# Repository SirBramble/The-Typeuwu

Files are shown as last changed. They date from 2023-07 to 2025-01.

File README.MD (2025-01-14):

# The Typeuwu

The Typeuwu is a modular keyboard design that can be extended with magnetic modules. It also provides a connector for a optional Bluetooth and Battery module.\
The firmware is written in C++ and provides a recompile free key remapping with the AniMacro scripting language.

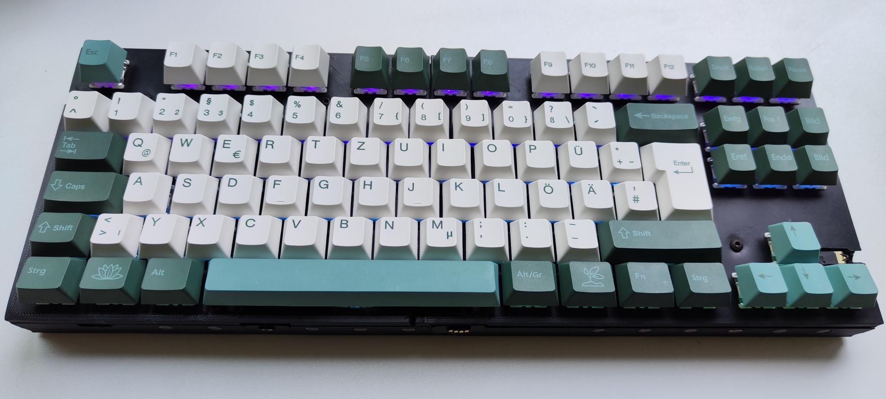
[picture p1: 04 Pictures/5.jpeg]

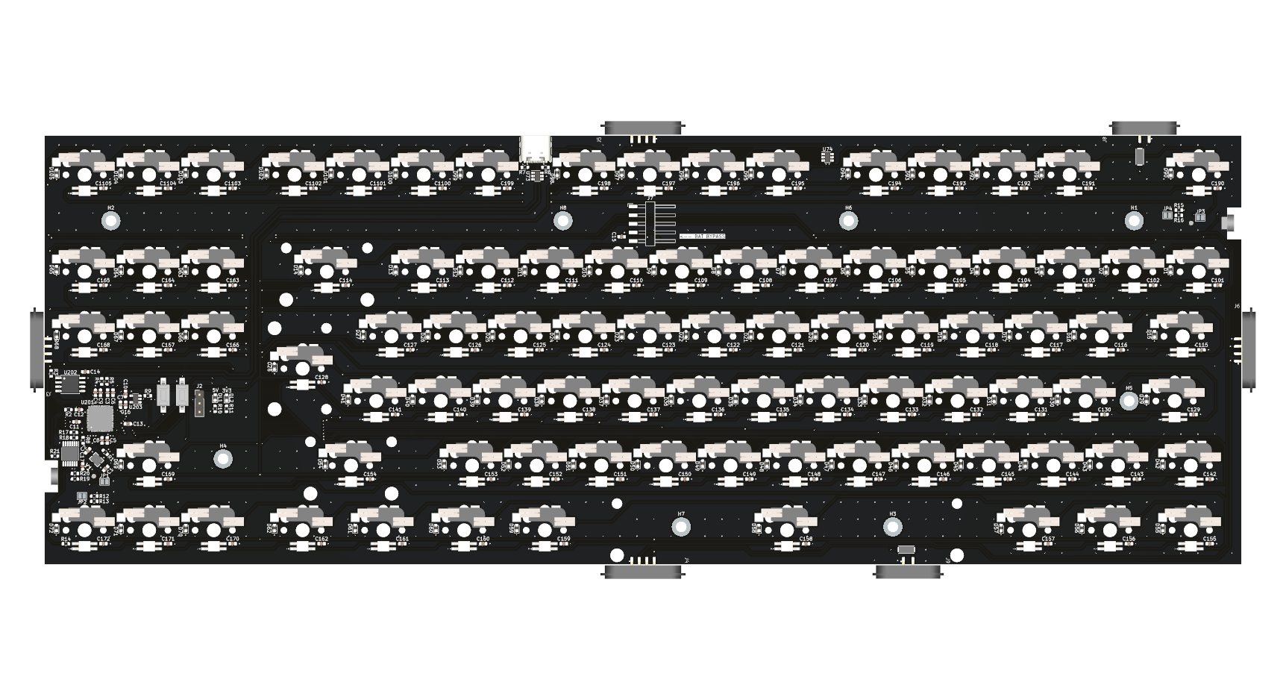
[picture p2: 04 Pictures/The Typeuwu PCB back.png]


## Hardware

The Typeuwu uses a RP2040 as the core processor, that polls the keyboard matrix, controls the LEDs and handles the communication between The keyboard and PC.

It also connects to the modules via magnetic pogo pin connectors located in the centre of each side. These provide the modules with power and expose the 5V level-shifted I2C lines.

Schematics can be found in ```/01 PCB/01 The Typeuwu PCB```.\
A PDF is available [```here```](01%20PCB/01%20The%20Typeuwu%20PCB/schematics/The%20Typeuwu.pdf).

## Firmware

The keyboard uses the custom written UWU (Universal Wordtyping Unit) Firmware that provides all needed interfaces for communicating with the Host and other modules.\
It also provides a parser for the 'AniMacro' scripting language, allowing the user to customise the key functionality from a config file located on the keyboards flash drive, without having to recompile the firmware.\

> [!IMPORTANT]  
> The firmware version included in this repository is deprecated. Though functional, further updates to the firmware will be posted to the [```UWU-Firmware```](https://github.com/SirBramble/UWU-Firmware) repository. Precompiled binary files are also available there.

### Uploading firmware

#### Precompiled firmware

To upload the precompiled binary, set the RP2040 into bootloader mode. This is done by first pressing the ```boot``` button, followed by either pressing the ```reset```button or performing a power cycle. The RP2040 should then mount as a flash drive named ```UF2```.\
Then either upload the Code using PIO or the Arduino IDE or copy the ```firmware.uf2``` file to the flash drive.

#### Compiling PIO

1. Make sure you have VSCode with the PlatformIO extension installed.
2. Clone the [```UWU-Firmware```](https://github.com/SirBramble/UWU-Firmware) repository (here: [github.com/SirBramble/UWU-Firmware](github.com/SirBramble/UWU-Firmware)).
3. Open the folder with PlatformIO.
   - PlatformIO should recognise it as a project and allow you to compile using either the VSCode interface or with the command ```platformio run```.
   - See [PlatformIO run documentation](https://docs.platformio.org/en/latest/core/userguide/cmd_run.html) for more information and possible arguments.
   - Any required library can either be added in the ```platformio.ini``` or copied to the ```lib``` (lib.h) and ```src``` (lib.c or lib.cpp) directory.

#### Compiling Arduino (deprecated)

1. Download the latest version of the Arduino IDE.
2. Install the [```arduino-pico```](https://github.com/earlephilhower/arduino-pico) board library.
    - You will also have to install the following librarys:
      - Adafruit NeoPixel (version: 1.12.0)
      - Adafruit SPIFlash (version: 4.3.1)
      - MIDI Library (version: 5.0.2)
3. Download the ```Typeuwu_Firmware``` folder.
4. Open the ```Typeuwu_Firmware.ino``` file with the Arduino IDE and either compile or upload directly.

## AniMacro scripting language

The 'AniMacro' scripting language allows the user to configure any Hardware Interface running the 'UWU firmware'.\
Configurations written in AniMacro are automatically loaded upon start-up and subsequently parsed using regular expressions. Additionally, the firmware can detect changes in the configuration file, facilitating its reload as needed, thereby enabling dynamic configuration adjustments at runtime.

A single configuration file accommodates configurations for various hardware UWU modules. The firmware selectively parses configurations pertinent to the currently connected hardware modules. This design choice allows for the seamless connection of multiple modules during runtime.

### Syntax

The 'AniMacro' syntax is based loosely on LaTeX syntax. A configuration for a specific module is wrapped in a ```begin``` and ```end``` qualifier:

```c
begin{module}
...
end{module}
```

Within a module configuration, multiple layers can be incorporated. Layers are a mechanism to implement diverse button configurations, facilitating dynamic switching between them at runtime. Layers can be added by typing ```Layer``` followed by the number of the layer:

```c
begin{module}
Layer x
...
end{module}
```

> [!IMPORTANT]
>By default the Firmware starts on layer 1. In the absence of a configured layer 1, the firmware remains inactive. It is advisable to consistently include a layer 1 configuration to ensure proper functionality.

All devices responsible for executing actions within a layer are designated using the ```Button``` keyword. Whether these devices are faders, potentiometers, or conventional buttons, they are uniformly referenced with the ```Button``` keyword.\
Buttons are implemented using the 'Button' keyword, followed by the button number, a colon, and a space. Subsequently, functionality can be added to the button by incorporating commands within the same line as the 'Button' keyword:

```c
begin{module}
Layer x
    Button a: commands
    Button b: commands
...
end{module}
```

Commands are categorized into several groups, which can be combined within a button configuration:

- Plain text:\
Entering plain text (e.g., "this is text123") utilizes the keyboard HID interface to type out the provided text.
    > [!NOTE]
    > Only ASCII characters are accepted in plain text. Non-ASCII characters (e.g. ```ä```) are managed with separate commands.
- ```\COMMAND``` with no arguments:\
    These commands serve as non-configurable placeholders for specific actions. For instance, pressing the 'Enter' key on the keyboard (```\ENTER_KEY```) or adding umlauts (```\ae``` => ```ä```).
- ```\COMMAND{}``` with arguments:\
    These commands are commonly employed to configure actions and callbacks within the firmware.\
    For example: ```\COLOR{const,green}``` would set the button to a constant green colour.\
    ```\MIDI_CC_KEY{16,1}\COLOR{midi,white}``` would configure a MIDI callback, binding the button to MIDI CC number 16 on MIDI channel 1. When the button is triggered, a MIDI message is dispatched to the host (PC), initiating an action. Subsequently, the host can relay back the state of the triggered action. The response from the host is then linked to the button colour, with a response greater than 126 denoting a triggered colour override, and a response of less than 126 signifying a reversion back to the layer default.

### List of commands

#### AniMacro commands

| Command | Description | Note |
| --- | --- | --- |
| Plain text | Types out the given text via the HID Interface | Only works with ASCII characters|
| ```\ae``` ```\oe``` ```\ue``` | Types out ```Umlauts``` (ä,ö,ü) | |
| ```\SZ_KEY``` | Sends keycode of ```ß``` key | |
| ```\GRAVE_KEY``` | Sends keycode of ```backtick``` ('´') key | |
| ```\CAPS_LOCK_KEY``` | Sends keycode of ```caps lock``` key | |
| ```\LSHIFT_KEY``` | Sends keycode of ```left shift``` key | |
| ```\RSHIFT_KEY``` | Sends keycode of ```right shift``` key | |
| ```\LCTRL_KEY``` | Sends keycode of ```left control``` key | For control combinations (e.g. ```CTRL``` + ```C```) refer to ```\STRG{char}```|
| ```\RCTRL_KEY``` | Sends keycode of ```right control``` key | For control combinations (e.g. ```CTRL``` + ```C```) refer to ```\STRG{char}```|
| ```\LATL_KEY``` | Sends keycode of ```left alt``` key | |
| ```\RATL_KEY```| Sends keycode of ```right alt``` key | |
| ```\WIN_KEY``` | Sends keycode of ```windows``` key | |
| ```\APP_KEY``` | Sends keycode of ```app``` key | |
| ```\RMETA_KEY``` | Sends keycode of ```right meta``` key | |
| ```\SPACE_KEY``` | Sends keycode of ```space bar``` key | Equivalent to typing space character in plain text |
| ```\BACKSPACE_KEY``` | Sends keycode of ```backspace``` key | |
| ```\DEL_KEY``` | Sends keycode of ```delete``` key | |
| ```ENTER_KEY``` | Sends keycode of ```enter``` key | |
| ```ESC_KEY``` | Sends keycode of ```escape``` key | |
| ```Tab_KEY``` | Sends keycode of ```tab``` key | |
| ```F[x]_KEY``` | Sends keycode of ```F[x]``` key | ```[x]``` to be replaced with number from ```1-12```|
| ```[arrow]_KEY``` | Sends keycode of ```[arrow]``` key | [arrow] to be replaced with one of: ```UP```, ```DOWN```, ```LEFT```, ```RIGHT```|
| ```[arrow]_KEY{[x]}```| Sends keycode of ```[arrow]``` key ```[x]``` times | ```[x]``` to be replaced with number and ```[arrow]``` to be replaced with one of: ```LEFT, RIGHT``` |
| ```\STRG{char}``` | Sends control combinations | Example: ```\STRG{c}``` => ```CTRL``` + ```C```|
| ```\MIDI_CC{[CT],[CH]}``` | Sends MIDI CC with number ```[CT]``` on MIDI channel ```[CH]``` with value from button | Replace ```[CT]``` with number from 0 to 127 and ```[CH]``` with number from 1-15. The button has to have a value or be a ```fader```/```potentiometer```/```encoder```.|
| ```\MIDI_CC_KEY{[CT],[CH]}``` | Sends MIDI CC with number ```[CT]``` on MIDI channel ```[CH]``` with value 127 | Replace ```[CT]``` with number from ```0``` to ```127``` and ```[CH]``` with number from ```1-15```. Used to trigger button events in software|
| ```\COLOR{[M],[C]}``` | Sets colour mode of button to ```[M]``` with colour ```[C]``` | Refer to ```colour mode list``` for valid mode ```[M]``` and ```colour list``` for valid colour ```[C]```|
| ```\COLOR{[M],[R],[G],[B]}``` | Sets colour mode of button to ```[M]``` with colour comprised of ```[R]```,```[G]``` and ```[B]``` | Refer to ```colour mode list``` for valid mode ```[M]```|
| ```\LAYER{[L]}``` | Sets active Layer to ```[L]``` | Layer ```[L]``` should be defined. Example: For ```\Layer{2}```, ```Layer 2``` should be defined.|

#### Colour mode list

|<div style="width:90px">Colour Mode</div> | Description | Note|
|:---|:---|:---|
| ```const``` | Sets a constant colour | |
| ```pressed``` | Sets the given colour if the button is triggered | |
| ```not pressed``` | Sets the given colour if the button is not triggered | |
| ```toggle``` | Toggles the colour on button trigger | |
| ```MIDI``` | Sets the colour based on message received over MIDI | Button has to be set as MIDI button with ```\MIDI_CC_KEY```. The channel and number set in ```\MIDI_CC_KEY``` will be used to trigger the colour|
| ```disabled``` | Disables the colour on the key | |

#### Colour list

|Colour|Note|
|:---|:---|
| ```red``` | |
| ```yellow``` | |
| ```green``` | |
|```cyan``` | |
| ```blue``` | |
| ```magenta``` | |
| ```white``` | |
| ```none/off``` | Used for modes, where colour is not a relevant parameter|

## Case

The Case for the Typeuwu is 3D-printed. Solidworks project files, STEP and STL files are included.

## Pictures

![Keyboard with module](04%20Pictures/20.jpeg)
![Keyboard](04%20Pictures/5.jpeg)
![Keyboard](04%20Pictures/The%20Typeuwu%20PCB%20back.png)
![Keyboard](04%20Pictures/The%20Typeuwu%20PCB%20front.png)

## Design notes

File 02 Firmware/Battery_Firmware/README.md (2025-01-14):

# README BLE/Battery Board

## Compilation instructions

First you will need the esp32 Core by Espressif.

**IMPORTANT:** You need to install Version *2.0.11*. The newer Versions feature a different String type in the *begin* function. This will cause compilation errors.

### Upload settings

In order of appearance:

- **Board:** "ESP32C3 Dev Module"
- **USB CDC On Boot:** "Disabled"
- **CPU Frequency** "160MHz (WiFi)"
- **Core Debug Level:** "None"
- **Erase All Flash Before Sketch Upload:** "Disabled"
- **Flash Frequency:** "80MHz"
- **Flash Mode:** "QIO"
- **Flash Size:** "2MB (16Mb)"
- **JTAG Adapter:** "Disabled"
- **Partition Scheme:** "Minimal (1.3MB APP/700KB SPIFFS)"
- **Upload Speed:** "921600"

## Config Options

 In ```BleKeyboard bleKeyboard("Typeuwu", "FG Labs", 69);``` the *Device Name*, *Manufacturer* and *Initial Battery Level* can be set.

In the ```receiveEvent``` function new/custom I²C commands can be added.

```c
while(Wire.available()){
reportID = Wire.read();
switch(reportID){
  case RID_KEYBOARD:
    tmp->modifiers = Wire.read();
    tmp->keys[0] = Wire.read();
    tmp->keys[1] = Wire.read();
    tmp->keys[2] = Wire.read();
    tmp->keys[3] = Wire.read();
    tmp->keys[4] = Wire.read();
    tmp->keys[5] = Wire.read();
    break;
  case 15:
    softDisableFlag = Wire.read();
    if(softDisableFlag != 0) softDisableFlag = true;
    break;
  default:
    Wire.read();
    break;
}
```

As of creation of the README, 2 functions have been implemented.

- Function 1 (ReportID = 1)
  - Reads a Key report
  - Order:
    - modifier: 1 byte
    - keys: 6 bytes
- Function 2 (ReportID = 15)
  - Sends ESP in to deep sleep
  - This is used to save power, when the Keyboard is connected and registered via USB HID.
- default (ReportID = *none of the above*)
  - voids the I²C buffer

To add a function

- assign a ReportID
- add a new case to the switch

## Troubleshooting

- Keyboard is connected, but doesn't send Keycodes
  1. Unpair Keyboard from Host
  2. power cycle the Keyboard
  3. Repair the Keyboard
- ESP stuck in boot loop
  1. Sorry to hear that :(
  2. Make sure the battery board is powered on correctly
     - If the Voltage converter is buzzing, you have a power problem
       - The Battery could be flat (or close to)
       - The board is not turned on properly (use the power toggle switch)
  3. Check the upload parameters
     - Try changing the *Flash Frequency* to *40MHz*

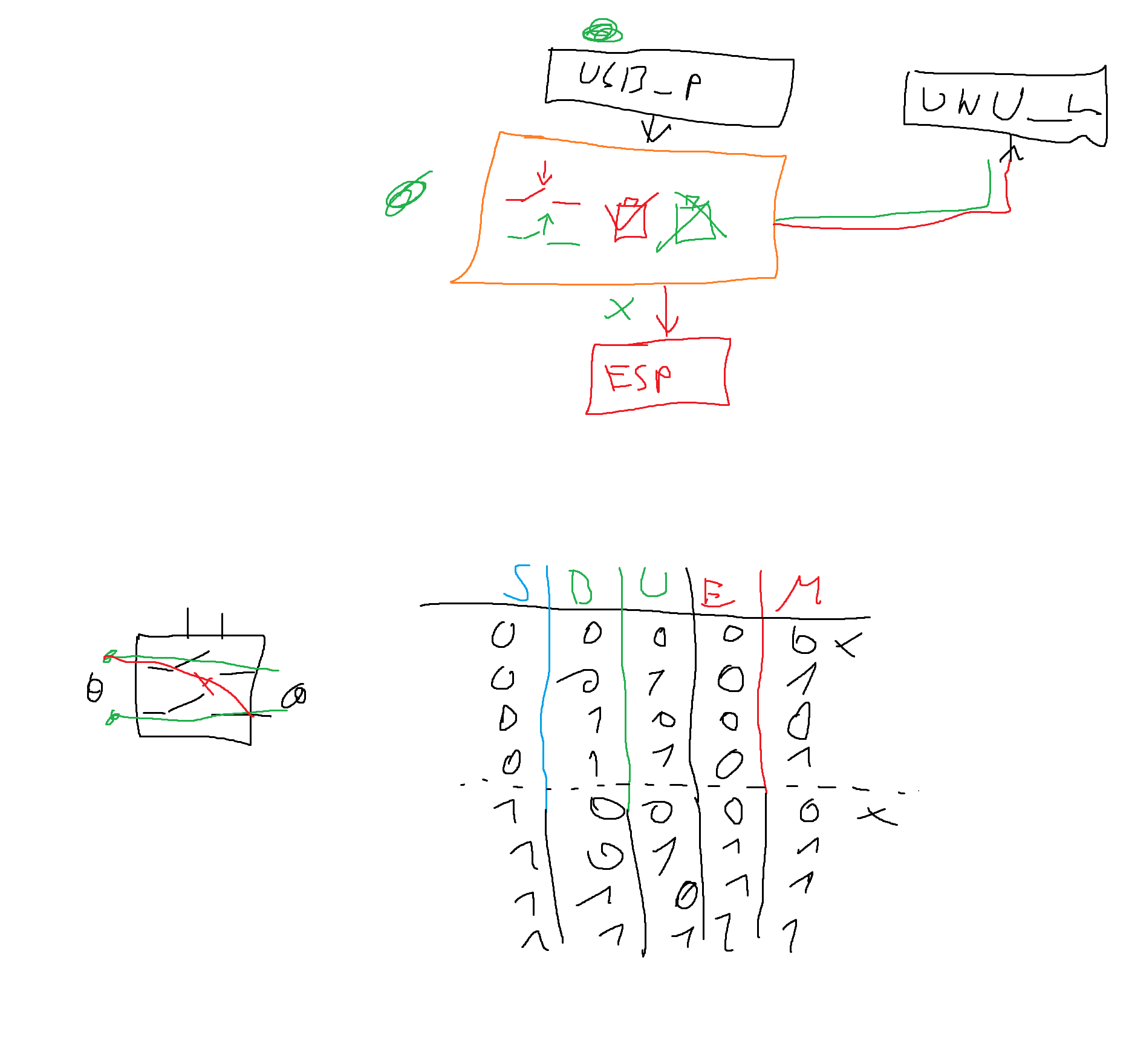
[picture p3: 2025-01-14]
01 PCB/02 Battery PCB/ref/Power Path.png

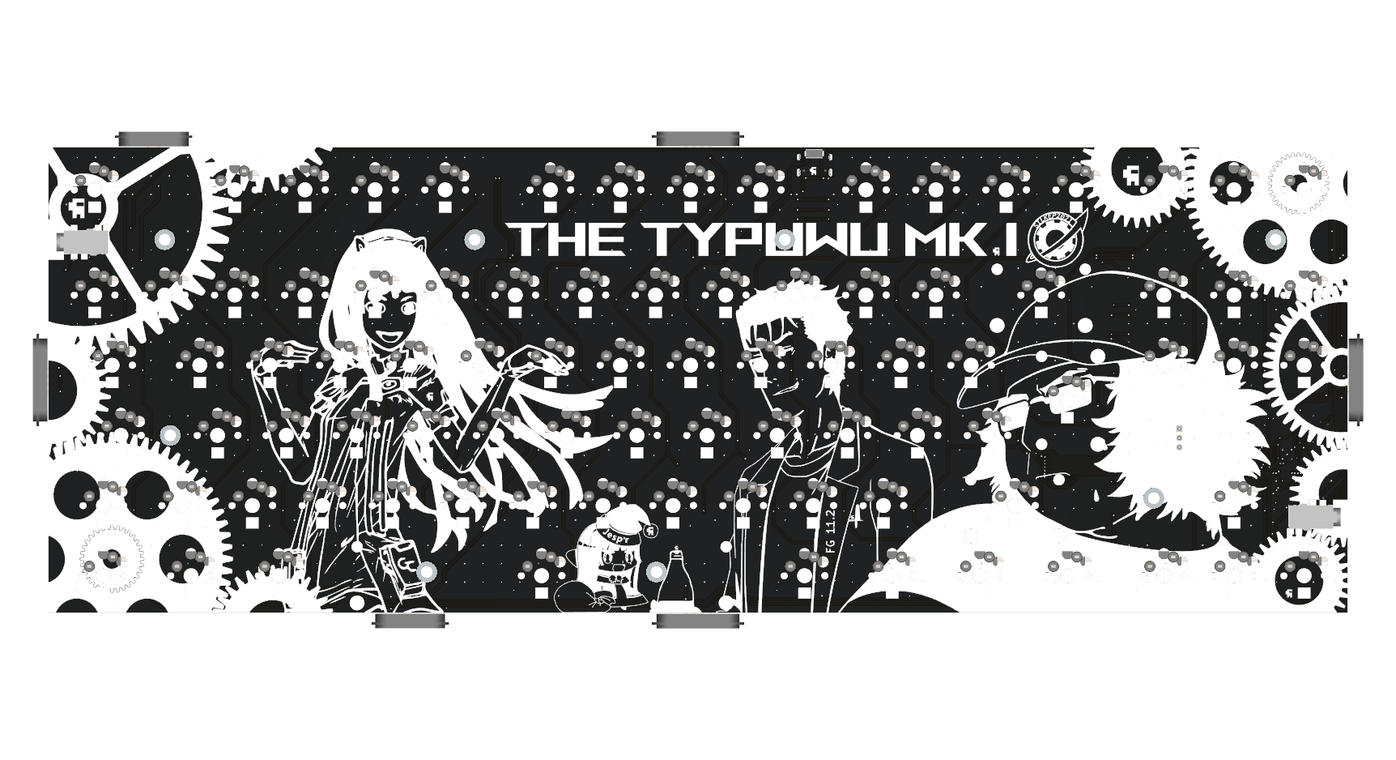
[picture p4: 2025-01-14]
04 Pictures/The Typeuwu PCB front.png

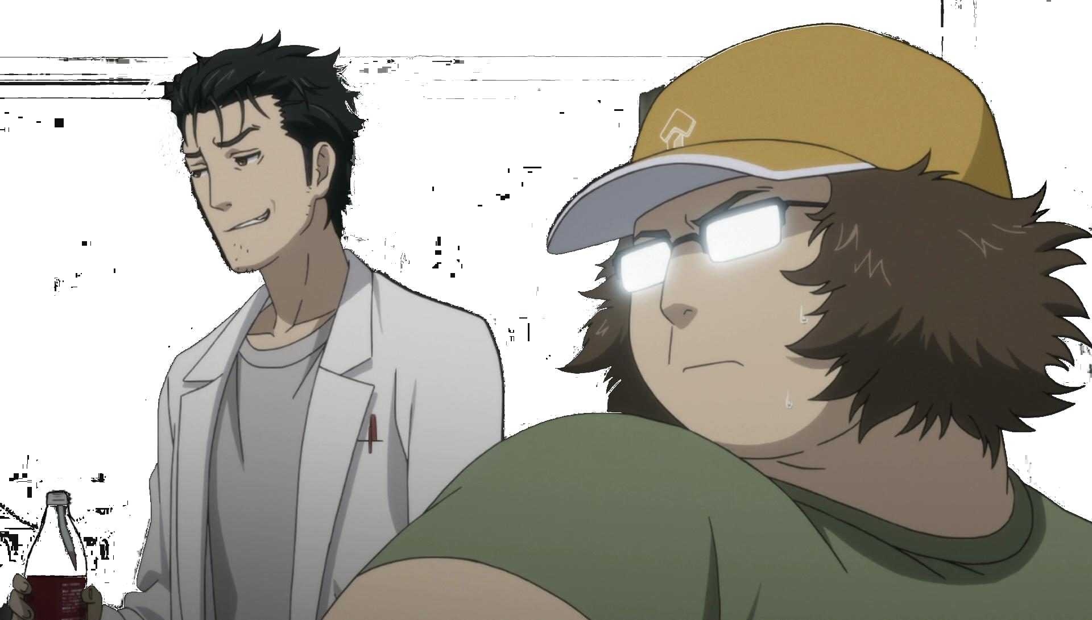
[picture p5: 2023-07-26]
01 PCB/01 The Typeuwu PCB/silkscreen/ref/Okabe and daru no Background.png

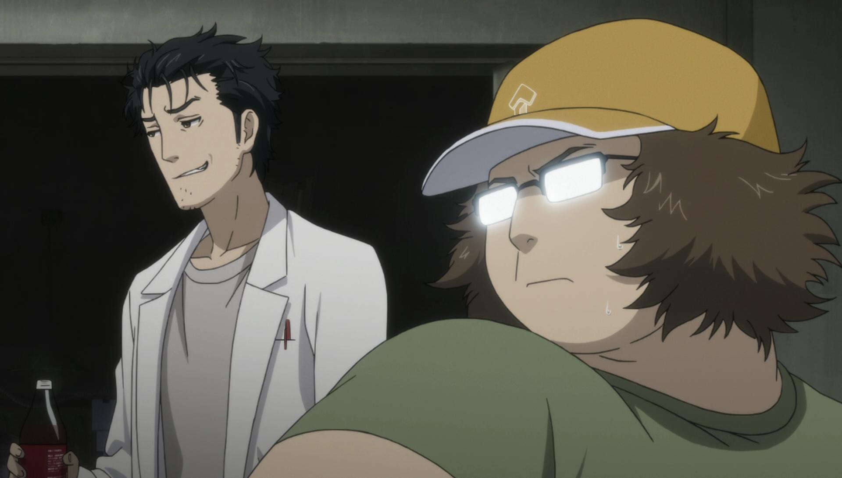
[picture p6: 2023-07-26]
01 PCB/01 The Typeuwu PCB/silkscreen/ref/Okabe and daru.png

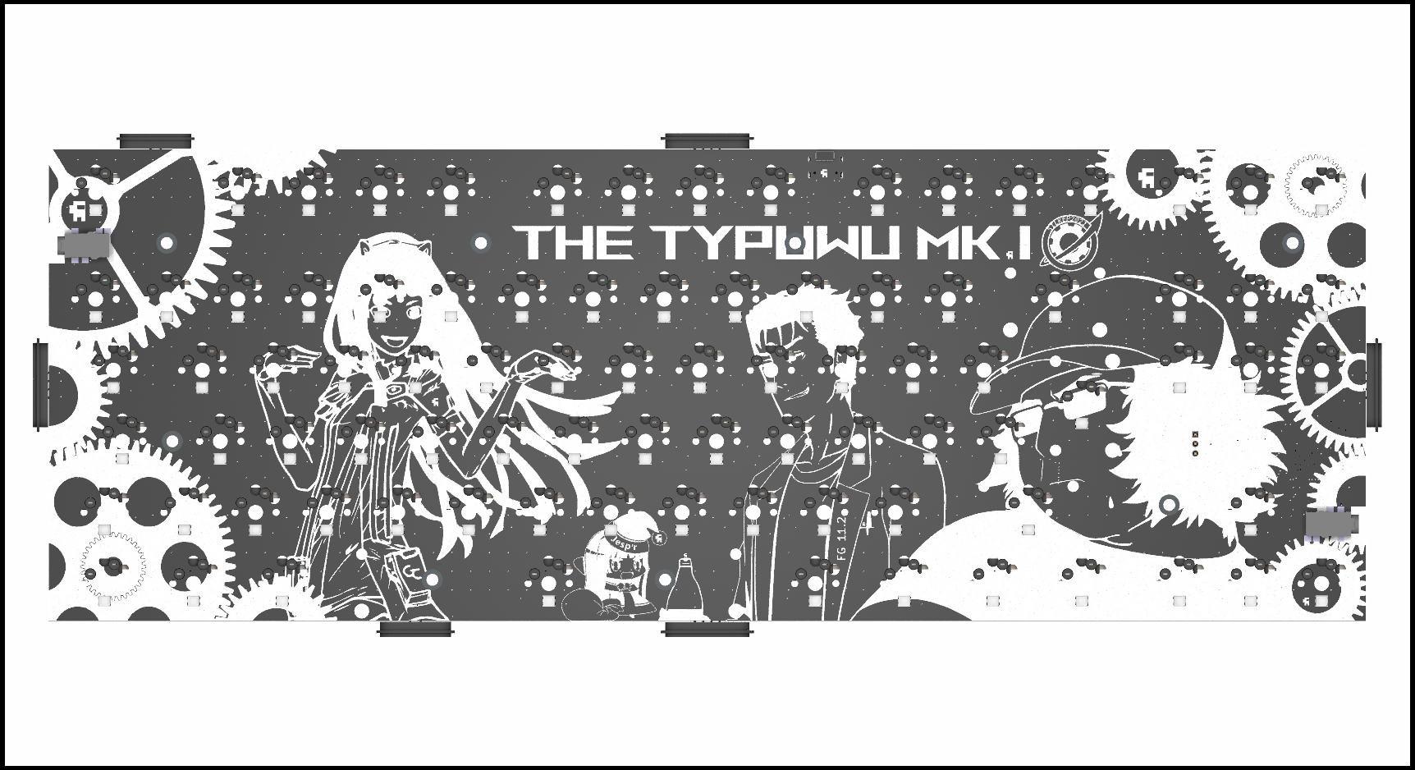
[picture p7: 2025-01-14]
04 Pictures/The Typeuwu PCB front_rt.png

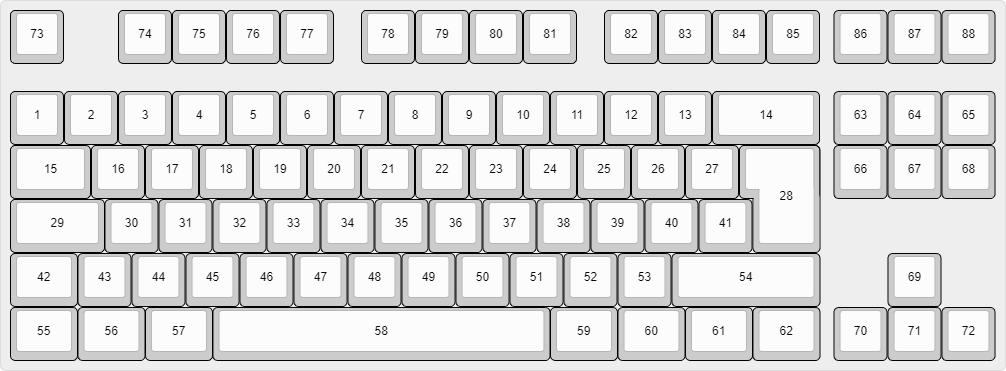
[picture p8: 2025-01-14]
02 Firmware/Typeuwu_Firmware/keyboard-layout.png

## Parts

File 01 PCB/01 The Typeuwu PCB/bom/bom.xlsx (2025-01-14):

Ammount Boards: | 5
References | Value | Footprint | Manufacturer_Part_Number | Mouser Part Number | Quantity
C4, C5, C7, C8, C9, C10, C11, C12, C13, C14, C17, C101, C102, C103, C104, C105, C106, C107, C108, C109, C110, C111, C112, C113, C114, C115, C116, C117, C118, C119, C120, C121, C122, C123, C124, C125, C126, C127, C128, C129, C130, C131, C132, C133, C134, C135, C136, C137, C138, C139, C140, C141, C142, C143, C144, C145, C146, C147, C148, C149, C150, C151, C152, C153, C154, C155, C156, C157, C158, C159, C160, C161, C162, C163, C164, C165, C166, C167, C168, C169, C170, C171, C172, C190, C191, C192, C193, C194, C195, C196, C197, C198, C199, C1100, C1101, C1102, C1103, C1104, C1105 | 100nF | C_0603_1608Metric | CC0603KRX5R9BB104 | 603-CC603KRX5R9BB104 (https://www.mouser.de/ProductDetail/YAGEO/CC0603KRX5R9BB104?qs=vkMqrgFpRaiQQdJI9SHamg%3D%3D) | 495
C3, C6, C15, C16 | 1u | C_0603_1608Metric | CL10A105KB8NNNC | 187-CL10A105KB8NNNC (https://www.mouser.de/ProductDetail/Samsung-Electro-Mechanics/CL10A105KB8NNNC?qs=ktYoCbbtCSJz4pFCLWXd5g%3D%3D) | 20
C1, C2 | 8pF | C_0603_1608Metric | 0603N8R0C500CT | 791-0603N8R0C500CT (https://www.mouser.de/ProductDetail/Walsin/0603N8R0C500CT?qs=ZrPdAQfJ6DORa%2FoFCfxEqw%3D%3D) | 10
R13, R16, R17, R18, R19, R20 | 2k2 | R_0603_1608Metric | RMC1/16K2201FTP | 791-RMC1/16K2201FTP (https://www.mouser.de/ProductDetail/Kamaya/RMC1-16K2201FTP?qs=sGAEpiMZZMtlubZbdhIBIA7Yl3UlZog1Dpd0uwqgtwE%3D) | 30
R1, R3, R10, R11, R12, R15, R21 | 1k | R_0603_1608Metric | CR0603AFX-1001EAS | 652-CR0603AFX1001EAS (https://www.mouser.de/ProductDetail/Bourns/CR0603AFX-1001EAS?qs=sGAEpiMZZMtlubZbdhIBIJFGDp18fIDTb9Qeg8MX0mE%3D) | 35
R2, R8, R9 | 10k | R_0603_1608Metric | CRT0603-FZ-1002ELF | 652-CRT0603FZ1002ELF (https://www.mouser.de/ProductDetail/Bourns/CRT0603-FZ-1002ELF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) | 15
R4, R5 | 27.4 | R_0603_1608Metric | CR0603-FX-27R4ELF | 652-CR0603FX-27R4ELF (https://www.mouser.de/ProductDetail/Bourns/CR0603-FX-27R4ELF) | 10
R6, R7 | 5k1 | R_0603_1608Metric | CR0603AFX-5101EAS | 652-CR0603AFX5101EAS (https://www.mouser.de/ProductDetail/Bourns/CR0603AFX-5101EAS) | 10
R14 | 330 | R_0603_1608Metric | CR0603-FX-3300ELF | 652-CR0603FX-3300ELF (https://www.mouser.de/ProductDetail/Bourns/CR0603-FX-3300ELF) | 5
D1, D2, D3, D4, D5, D6, D7, D8, D9, D10, D11, D12, D13, D14, D15, D16, D17, D18, D19, D20, D21, D22, D23, D24, D25, D26, D27, D28, D29, D30, D31, D32, D33, D34, D35, D36, D37, D38, D39, D40, D41, D42, D43, D44, D45, D46, D47, D48, D49, D50, D51, D52, D53, D54, D55, D56, D57, D58, D59, D60, D61, D62, D63, D64, D65, D66, D67, D68, D69, D70, D71, D72, D90, D91, D92, D93, D94, D95, D96, D97, D98, D99, D100, D101, D102, D103, D104, D105 | D_Small | D_0603_1608Metric | CDBU40-HF Alternative: BAS16TS_R1_00001 | 750-CDBU40-HF (https://www.mouser.de/ProductDetail/Comchip-Technology/CDBU40-HF?qs=2qJf6qQ4IOJyq8K2kYdToA%3D%3D) | 440
D01, D02, D03 | CD214A-B240LR | CD214A-B240LR | CD214A-B240LR | 652-CD214A-B240LR (https://www.mouser.de/ProductDetail/Bourns/CD214A-B240LR?qs=f9yNj16SXrLocD1dV%2FObRw%3D%3D) | 15
U1, U2, U3, U4, U5, U6, U7, U8, U9, U10, U11, U12, U13, U16, U17, U18, U19, U20, U21, U22, U23, U24, U25, U26, U27, U30, U31, U32, U33, U34, U35, U36, U37, U38, U39, U40, U41, U43, U44, U45, U46, U47, U48, U49, U50, U51, U52, U53, U63, U64, U65, U66, U67, U68, U69, U70, U71, U72, U90, U91, U92, U93, U94, U95, U96, U97, U98, U99, U100, U101, U102, U103, U104, U105 | Multi_Hotswap_with_RGB | Multi Hotswap with RGB 1U | - | - | 370
U42, U55, U56, U57, U59, U60, U61, U62 | Multi_Hotswap_with_RGB | Multi Hotswap with RGB 1,25U | - | - | 40
U73, U74 | SRV05-4 | SOT-23-6 | SRV05-4L-TP | 833-SRV05-4L-TP (https://www.mouser.de/ProductDetail/Micro-Commercial-Components-MCC/SRV05-4L-TP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) | 10
U14 | Multi_Hotswap_with_RGB | Multi Hotswap with RGB 2U | - | - | 5
U15 | Multi_Hotswap_with_RGB | Multi Hotswap with RGB 1,5U | - | - | 5
U28 | Multi_Hotswap_with_RGB | Multi Hotswap with RGB ISO Enter | - | - | 5
U29 | Multi_Hotswap_with_RGB | Multi Hotswap with RGB 1,75U | - | - | 5
U54 | Multi_Hotswap_with_RGB | Multi Hotswap with RGB 2,75U | - | - | 5
U58 | Multi_Hotswap_with_RGB | Multi Hotswap with RGB 6,25U | - | - | 5
U201 | RP2040 | QFN-56-1EP_7x7mm_P0.4mm_EP3.2x3.2mm | SC0914(13) | 358-SC091413 (https://www.mouser.de/ProductDetail/Raspberry-Pi/SC091413?qs=T%252BzbugeAwjhr%252BUbBr3TJcw%3D%3D) | 5
U202 | W25Q128JVS | SOIC-8_5.23x5.23mm_P1.27mm | W25Q128JVSIQ TR | 454-W25Q128JVSIQTR (https://www.mouser.de/ProductDetail/Winbond/W25Q128JVSIQ-TR?qs=qSfuJ%252Bfl%2Fd7vTyLA9kNdGw%3D%3D) | 5
U203 | AP2112K-3.3 | SOT-23-5 | AP2112K-3.3TRG1 | 621-AP2112K-3.3TRG1 (https://www.mouser.de/ProductDetail/Diodes-Incorporated/AP2112K-3.3TRG1?qs=x6A8l6qLYDDPYHosCdzh%2FA%3D%3D) | 5
Y1 | NX3225SA-12.000000MHZ | NX3225SA12MHZSTDCSR3 | NX3225SA-12MHZ-STD-CSR-3 | 344-NX3225SA12MCSR3 (https://www.mouser.de/ProductDetail/NDK/NX3225SA-12MHZ-STD-CSR-3?qs=55YtniHzbhCJWHkuFk0FIQ%3D%3D) | 5
SW1 | BOOT | PTS636SP50SMTRLFS | PTS636 SP50 SMTR LFS | 611-PTS636SP50SMTRLF (https://www.mouser.de/ProductDetail/CK/PTS636-SP50-SMTR-LFS?qs=vLWxofP3U2yQrwr1QnrRJw%3D%3D) | 5
SW2 | RESET | PTS636SP50SMTRLFS | PTS636 SP50 SMTR LFS | 611-PTS636SP50SMTRLF (https://www.mouser.de/ProductDetail/CK/PTS636-SP50-SMTR-LFS?qs=vLWxofP3U2yQrwr1QnrRJw%3D%3D) | 5
H1, H2, H3, H4, H5, H6, H7, H8 | MountingHole | MountingHole_3.2mm_M3_DIN965_Pad | - | - | 40
JP1, JP3 | SolderJumper_2_Bridged | SolderJumper-2_P1.3mm_Bridged_Pad1.0x1.5mm | - | - | 10
JP2, JP4 | SolderJumper_2_Open | SolderJumper-2_P1.3mm_Open_Pad1.0x1.5mm | - | - | 10
S1, S2 | SJ2-35954B-SMT-TR | SJ235954BSMTTR | SJ2-35954B-SMT-TR | 490-SJ2-35954BSMT-TR (https://www.mouser.de/ProductDetail/CUI-Devices/SJ2-35954B-SMT-TR?qs=DXv0QSHKF4xFg%252BzFD15Yig%3D%3D) | 10
STAB14, STAB54 | ~ | Stabilizer_Cherry_MX_2.00u | Durock Screw in Stabilizer V2 | LINK (https://keycapsss.com/keyboard-parts/parts/153/durock-pcb-mount-screw-in-stabilizer-v2?number=KC10119_MVTP-Set) | 10
DL1 | PWR_5V | D_0603_1608Metric | - | - | 5
DL2 | PWR_3V3 | D_0603_1608Metric | - | - | 5
IC1 | LSF0204QPWRQ1 | SOP65P640X120-14N | LSF0204QPWRQ1 | 595-LSF0204QPWRQ1 (https://www.mouser.de/ProductDetail/Texas-Instruments/LSF0204QPWRQ1?qs=w%2Fv1CP2dgqqt88p%2F1xId1A%3D%3D) | 5
STAB58 | ~ | Stabilizer_Cherry_MX_6.25u | Durock Screw in Stabilizer V2 | LINK (https://keycapsss.com/keyboard-parts/parts/153/durock-pcb-mount-screw-in-stabilizer-v2?number=KC10119_MVTP-Set) | 5
J3, J4, J5, J6 | Conn_01x04 | POGO Magnetic 4 Pin 2,2mm Horizontal | - | - | 20
J8, J9 | Conn_01x02 | POGO Magnetic 2 Pin 2,8mm Horizontal | - | - | 10
J1 | USB_C_Receptacle_USB2.0 | USB_C_Receptacle_GCT_USB4105-xx-A_16P_TopMnt_Horizontal | USB4105-GF-A | 640-USB4105-GF-A (https://www.mouser.de/ProductDetail/GCT/USB4105-GF-A?qs=KUoIvG%2F9IlY%2FMLlBMpStpA%3D%3D) | 5
J2 | DEBUG | PinHeader_1x03_P2.54mm_Vertical | - | - | 5
J7 | M20-8900505 | Harwin_M20-89005xx_1x05_P2.54mm_Horizontal | M20-8900505 | 855-M20-8900505 (https://www.mouser.de/ProductDetail/Harwin/M20-8900505?qs=vF78I%252BjhbY%2F3PhBxZY8XIA%3D%3D) | 5

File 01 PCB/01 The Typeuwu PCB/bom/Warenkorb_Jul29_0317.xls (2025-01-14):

WARENKORB
Dies ist keine Rechnung
29-Jul-23 15:17:31
 | Mouser-Nr. | Herst.- Nr. | Hersteller | Kunden-Teilenr | Beschreibung | RoHS | Lebenszyklus | Stückzahl | Preis (EUR) | Gesamtpreis: (EUR)
1 | 603-CC603KRX5R9BB104 | CC0603KRX5R9BB104 | YAGEO |  | Kondensator aus mehreren Keramikschichten MLCC - SMD/SMT 50 V 0.1uF X5R 0603 10% | RoHS-konform |  | 500 | 0,015 € | 7,50 €
2 | 187-CL10A105KB8NNNC | CL10A105KB8NNNC | Samsung Electro-Mechanics |  | Kondensator aus mehreren Keramikschichten MLCC - SMD/SMT 1uF+/-10% 50V X5R 16 0603 | RoHS-konform |  | 25 | 0,077 € | 1,93 €
3 | 791-0603N8R0C500CT | 0603N8R0C500CT | Walsin |  | Kondensator aus mehreren Keramikschichten MLCC - SMD/SMT 8.0pF +-0.25% 50V | RoHS-konform |  | 10 | 0,046 € | 0,46 €
4 | 791-RMC1/16K2201FTP | RMC1/16K2201FTP | Kamaya |  | Dickfilmwiderstände - SMD 0603 2K2 1% Lead Free | RoHS: Konform durch Ausnahmegenehmigung |  | 30 | 0,012 € | 0,36 €
5 | 652-CR0603AFX1001EAS | CR0603AFX-1001EAS | Bourns |  | Dickfilmwiderstände - SMD 1K OHM 1% | RoHS: Konform durch Ausnahmegenehmigung |  | 35 | 0,015 € | 0,53 €
6 | 652-CRT0603FZ1002ELF | CRT0603-FZ-1002ELF | Bourns |  | Dünnfilmwiderstände - SMD CHIP RESISTOR Precision | RoHS-konform |  | 20 | 0,041 € | 0,82 €
7 | 652-CR0603FX-27R4ELF | CR0603-FX-27R4ELF | Bourns |  | Dickfilmwiderstände - SMD 27.4 ohm 1% | RoHS: Konform durch Ausnahmegenehmigung |  | 10 | 0,012 € | 0,12 €
8 | 652-CR0603AFX5101EAS | CR0603AFX-5101EAS | Bourns |  | Dickfilmwiderstände - SMD ResA-AS 0603 5k1 1% 100mW TC100 | RoHS: Konform durch Ausnahmegenehmigung |  | 10 | 0,015 € | 0,15 €
9 | 652-CR0603FX-3300ELF | CR0603-FX-3300ELF | Bourns |  | Dickfilmwiderstände - SMD 330 ohm 1% | RoHS: Konform durch Ausnahmegenehmigung |  | 10 | 0,008 € | 0,08 €
10 | 652-CD214A-B240LR | CD214A-B240LR | Bourns |  | Schottky Dioden & Gleichrichter 40V 2A | RoHS-konform |  | 15 | 0,33 € | 4,95 €
11 | 833-SRV05-4L-TP | SRV05-4L-TP | Micro Commercial Components (MCC) |  | ESD-Entstörer/TVS-Dioden 5V, 2.0uA 5V, 2.0uA | RoHS-konform |  | 10 | 0,313 € | 3,13 €
12 | 358-SC091413 | SC0914(13) | Raspberry Pi |  | ARM Mikrocontroller - MCU IC RP2040 (RP2B2) T&R, 3,400 (13" reel) UICC01104 |  | Neu bei Mouser | 5 | 0,63 € | 3,15 €
13 | 454-W25Q128JVSIQTR | W25Q128JVSIQ TR | Winbond |  | NOR-Flash spiFlash, 3V, 128M-bit, 4Kb Uniform Sector | RoHS-konform |  | 5 | 1,63 € | 8,15 €
14 | 621-AP2112K-3.3TRG1 | AP2112K-3.3TRG1 | Diodes Incorporated |  | LDO Spannungs-Regulator 600mA CMOS LDO 50mA 3.3V 250mV | RoHS-konform |  | 5 | 0,333 € | 1,67 €
15 | 344-NX3225SA12MCSR3 | NX3225SA-12MHZ-STD-CSR-3 | NDK |  | Quarze CRYSTAL 12MHZ 8PF SMD | RoHS-konform |  | 5 | 0,621 € | 3,11 €
16 | 611-PTS636SP50SMTRLF | PTS636 SP50 SMTR LFS | C&K Switches |  | Sensorschalter Tact 50mA 12VDC, 6.0x3.5, 5.0mm H, 320gf, G leads, No ground pin, Black Actuator | RoHS-konform |  | 10 | 0,098 € | 0,98 €
17 | 640-USB4105-GF-A | USB4105-GF-A | Global Connector Technology (GCT) |  | USB-Stecker USB Type C,2.0, Rec,SMT, 0.95mmTH Shell Stakes,G/F,RA,Top Mnt,T&R | RoHS-konform |  | 5 | 0,72 € | 3,60 €
18 | 855-M20-8900505 | M20-8900505 | Harwin |  | Sockel & Kabelgehäuse 5 SIL HORIZONTAL SMT HEADER GOLD | RoHS-konform |  | 5 | 0,657 € | 3,29 €
19 | 863-RB521S30T5G | RB521S30T5G | onsemi |  | Schottky Dioden & Gleichrichter SCHOTTKY DIODE | RoHS-konform |  | 500 | 0,045 € | 22,50 €
Durch das Absenden Ihrer Bestellung erklären Sie sich mit diesen Geschäftsbedingungen einverstanden. (https://www.mouser.de/saleterms) |  |  |  |  |  |  |  |  | Ware: | 66,48 €
Die Preise sind zum angezeigten Datum und zur Uhrzeit reflektiert. |  |  |  |  |  |  |  |  | Versandkosten: | 0,00 €

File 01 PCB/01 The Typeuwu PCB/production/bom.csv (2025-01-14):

Designator | Footprint | Quantity | Value | LCSC Part #
C1, C2 | 0603 | 2 | 8pF
C10, C101, C102, C103, C104, C105, C106, C107, C108, C109, C11, C110, C1100, C1101, C1102, C1103, C1104, C1105, C111, C112, C113, C114, C115, C116, C117, C118, C119, C12, C120, C121, C122, C123, C124, C125, C126, C127, C128, C129, C13, C130, C131, C132, C133, C134, C135, C136, C137, C138, C139, C14, C140, C141, C142, C143, C144, C145, C146, C147, C148, C149, C150, C151, C152, C153, C154, C155, C156, C157, C158, C159, C160, C161, C162, C163, C164, C165, C166, C167, C168, C169, C17, C170, C171, C172, C190, C191, C192, C193, C194, C195, C196, C197, C198, C199, C4, C5, C7, C8, C9 | 0603 | 99 | 100nF
C15, C16, C3, C6 | 0603 | 4 | 1u
D01, D02, D03 | CD214A-B240LR | 3 | CD214A-B240LR
D1, D10, D100, D101, D102, D103, D104, D105, D11, D12, D13, D14, D15, D16, D17, D18, D19, D2, D20, D21, D22, D23, D24, D25, D26, D27, D28, D29, D3, D30, D31, D32, D33, D34, D35, D36, D37, D38, D39, D4, D40, D41, D42, D43, D44, D45, D46, D47, D48, D49, D5, D50, D51, D52, D53, D54, D55, D56, D57, D58, D59, D6, D60, D61, D62, D63, D64, D65, D66, D67, D68, D69, D7, D70, D71, D72, D8, D9, D90, D91, D92, D93, D94, D95, D96, D97, D98, D99 | 0603 | 88 | D_Small
DL1 | 0603 | 1 | PWR_5V
DL2 | 0603 | 1 | PWR_3V3
H1, H2, H3, H4, H5, H6, H7, H8 | MountingHole_3.2mm_M3_DIN965_Pad | 8 | MountingHole
IC1 | SOP65P640X120-14N | 1 | LSF0204QPWRQ1
J1 | USB_C_Receptacle_GCT_USB4105-xx-A_16P_TopMnt_Horizontal | 1 | USB_C_Receptacle_USB2.0
J2 | PinHeader_1x03_P2.54mm_Vertical | 1 | DEBUG
J3, J4, J5, J6 | POGO Magnetic 4 Pin 2,2mm Horizontal | 4 | Conn_01x04
J7 | Harwin_M20-89005xx_1x05_P2.54mm_Horizontal | 1 | M20-8900505
J8, J9 | POGO Magnetic 2 Pin 2,8mm Horizontal | 2 | Conn_01x02
JP1, JP3 | SolderJumper-2_P1.3mm_Bridged_Pad1.0x1.5mm | 2 | SolderJumper_2_Bridged
JP2, JP4 | SolderJumper-2_P1.3mm_Open_Pad1.0x1.5mm | 2 | SolderJumper_2_Open
R1, R12, R15, R21, R3 | 0603 | 5 | 1k
R10, R11 | 0603 | 2 | R
R13, R16, R17, R18, R19, R20 | 0603 | 6 | 2k2
R14 | 0603 | 1 | 330
R2, R8, R9 | 0603 | 3 | 10k
R4, R5 | 0603 | 2 | 27.4
R6, R7 | 0603 | 2 | 5k1
S1, S2 | SJ235954BSMTTR | 2 | SJ2-35954B-SMT-TR
STAB14, STAB54 | Stabilizer_Cherry_MX_2.00u | 2 | ~
STAB58 | Stabilizer_Cherry_MX_6.25u | 1 | ~
SW1 | PTS636SP50SMTRLFS | 1 | BOOT
SW2 | PTS636SP50SMTRLFS | 1 | RESET
U1, U10, U100, U101, U102, U103, U104, U105, U11, U12, U13, U16, U17, U18, U19, U2, U20, U21, U22, U23, U24, U25, U26, U27, U3, U30, U31, U32, U33, U34, U35, U36, U37, U38, U39, U4, U40, U41, U43, U44, U45, U46, U47, U48, U49, U5, U50, U51, U52, U53, U6, U63, U64, U65, U66, U67, U68, U69, U7, U70, U71, U72, U8, U9, U90, U91, U92, U93, U94, U95, U96, U97, U98, U99 | Multi Hotswap with RGB 1U | 74 | Multi_Hotswap_with_RGB
U14 | Multi Hotswap with RGB 2U | 1 | Multi_Hotswap_with_RGB
U15 | Multi Hotswap with RGB 1,5U | 1 | Multi_Hotswap_with_RGB
U201 | QFN-56-1EP_7x7mm_P0.4mm_EP3.2x3.2mm | 1 | RP2040
U202 | SOIC-8_5.23x5.23mm_P1.27mm | 1 | W25Q128JVS
U203 | SOT-23-5 | 1 | AP2112K-3.3
U28 | Multi Hotswap with RGB ISO Enter | 1 | Multi_Hotswap_with_RGB
U29 | Multi Hotswap with RGB 1,75U | 1 | Multi_Hotswap_with_RGB
U42, U55, U56, U57, U59, U60, U61, U62 | Multi Hotswap with RGB 1,25U | 8 | Multi_Hotswap_with_RGB
U54 | Multi Hotswap with RGB 2,75U | 1 | Multi_Hotswap_with_RGB
U58 | Multi Hotswap with RGB 6,25U | 1 | Multi_Hotswap_with_RGB
U73, U74 | SOT-23-6 | 2 | SRV05-4
Y1 | NX3225SA12MHZSTDCSR3 | 1 | NX3225SA-12.000000MHZ

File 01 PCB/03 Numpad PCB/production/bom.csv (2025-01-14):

Designator | Footprint | Quantity | Value | LCSC Part #
C1, C10, C11, C12, C13, C14, C15, C16, C17, C18, C19, C2, C20, C24, C25, C26, C27, C28, C29, C3, C4, C5, C6, C7, C8, C9 | 0603 | 26 | 100nF
C21 | 0603 | 1 | 1uF
C22, C23 | 0603 | 2 | 22pF
D1, D10, D11, D12, D13, D14, D15, D16, D17, D2, D3, D4, D5, D6, D7, D8, D9 | 0603 | 17 | D_Small
J1 | MC096VX and SSD1306 Display module 0.96” | 1 | Display 1
J2 | Tag-Connect_TC2030-IDC-NL_2x03_P1.27mm_Vertical | 1 | AVR-ISP-6
J3 | MC096VX and SSD1306 Display module 0.96” | 1 | Display 2
J4, J5, J6, J7 | POGO Magnetic 4 Pin 2,2mm Horizontal | 4 | Conn_01x04
R1, R3, R4, R5, R6 | 0603 | 5 | 10k
R2 | 0603 | 1 | 330
RV1, RV2 | Potentiometer_Bourns_PTA6043_Single_Slide | 2 | PTA6043-2010CIB502
U1, U10, U11, U12, U13, U14, U17, U2, U21, U22, U3, U4, U5, U6, U7, U9 | Multi Hotswap with RGB 1U | 16 | Multi_Hotswap_with_RGB
U15, U8 | Multi Hotswap with RGB 2U 90deg | 2 | Multi_Hotswap_with_RGB
U16 | Multi Hotswap with RGB 2U | 1 | Multi_Hotswap_with_RGB
U18 | TQFP-32_7x7mm_P0.8mm | 1 | ATmega328PB-A
U19 | SN74LVC2G17DCKR | 1 | ~
U20 | Alps EC12 with Neopixel | 1 | ~
Y1 | Crystal_SMD_HC49-SD | 1 | ABLS-16.000MHZ-D-3-Y-T

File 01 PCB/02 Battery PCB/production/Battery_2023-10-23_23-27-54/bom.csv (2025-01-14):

Designator | Footprint | Quantity | Value | LCSC Part #
C1, C2 | 0603 | 2 | 10p
C10, C5, C9 | 0603 | 3 | 10u
C11, C14, C15, C22, C27, C28, C29, C3, C30, C31, C4, C6, C7, C8 | 0603 | 14 | 100n
C12, C13 | 0603 | 2 | 3p3
C16, C17 | 0603 | 2 | 4.7 uF
C18, C21 | 0603 | 2 | 10uF
C19, C20 | 0805 | 2 | 10uF
C23, C24, C25 | 0805 | 3 | 22uF
C26 | 0603 | 1 | 1u
D1 | CD214A-B240LR | 1 | CD214A-B240LR
D2 | 155124RS73200 | 1 | LED green
D3 | 155124RS73200 | 1 | LED red
D4, D5 | D_SOD-523 | 2 | RB21S30T5G
D6, D7 | 0603 | 2 | LED
IC1 | SOP65P640X120-14N | 1 | LSF0204QPWRQ1
IC2 | SON50P300X200X60-9N | 1 | W25Q16JVUXIQ_TR
IC3 | TPS630701RNMR | 1 | TPS630701RNMR
J1 | USB_C_Receptacle_GCT_USB4105-xx-A_16P_TopMnt_Horizontal | 1 | USB_C_Receptacle_USB2.0
J2 | JST_PH_S2B-PH-SM4-TB_1x02-1MP_P2.00mm_Horizontal | 1 | BATTERY
J3 | 23370191 | 1 | 2337019-1
J5 | Harwin_M20-89005xx_1x05_P2.54mm_Horizontal | 1 | M20-8900505
L1, L2, L4 | 0603 | 3 | 2n2
L3 | EATON_EXL1V0402_4.6mmx4.6mm | 1 | 1.5uH
Q1, Q2 | TBAT54CLM | 2 | T2N7002AK,LM
R1, R10, R2, R4, R5, R6, R7 | 0603 | 7 | 5k1
R11, R14, R15, R17, R19, R21 | 0603 | 6 | 10k
R12, R13 | 0603 | 2 | 1.18k
R16 | 0603 | 1 | 100k
R18, R22, R23, R24, R25 | 0603 | 5 | 1k
R20 | 0603 | 1 | 22k
R3 | 0603 | 1 | 22
R8, R9 | 0603 | 2 | 510
SW1, SW2 | PTS636SP50SMTRLFS | 2 | PTS636 SP50
SW3 | SLW-864547-5A-RA-D | 1 | POWER SWITCH
U1 | QFN-32-1EP_5x5mm_P0.5mm_EP3.7x3.7mm_ThermalVias | 1 | ESP32C3
U2 | SOT-23-6 | 1 | USBLC6-2SC6
U4 | VQFN-16-1EP_3x3mm_P0.5mm_EP1.6x1.6mm | 1 | BQ24075RGT
U5 | SOT-23-5 | 1 | AP2112K-3.3
Y1 | Crystal_SMD_2016-4Pin_2.0x1.6mm | 1 | ECS-400-10-37B2-CKM-TR

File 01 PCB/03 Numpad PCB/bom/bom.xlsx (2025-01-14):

Ammount Boards: | 5
References | Value | Footprint | Manufacturer_Part_Number | Mouser Part Number | Quantity
C1, C2, C3, C4, C5, C6, C7, C8, C9, C10, C11, C12, C13, C14, C15, C16, C17, C18, C19, C20, C24, C25, C26, C27, C28, C29 | 100nF | C_0603_1608Metric | CC0603KRX5R9BB104 | 603-CC603KRX5R9BB104 (https://www.mouser.de/ProductDetail/YAGEO/CC0603KRX5R9BB104?qs=vkMqrgFpRaiQQdJI9SHamg%3D%3D) | 130
C22, C23 | 22pF | C_0603_1608Metric | 0201N220J500CT | 791-0201N220J500CT (https://www.mouser.de/ProductDetail/Walsin/0201N220J500CT?qs=ZrPdAQfJ6DPdpqqdjdResA%3D%3D) | 10
C21 | 1uF | C_0603_1608Metric | CL10A105KB8NNNC | 187-CL10A105KB8NNNC (https://www.mouser.de/ProductDetail/Samsung-Electro-Mechanics/CL10A105KB8NNNC?qs=ktYoCbbtCSJz4pFCLWXd5g%3D%3D) | 5
R1, R3, R4, R5, R6 | 10k | R_0603_1608Metric | CRT0603-FZ-1002ELF | 652-CRT0603FZ1002ELF (https://www.mouser.de/ProductDetail/Bourns/CRT0603-FZ-1002ELF?qs=oyIm%2F3giSj6U5mW%252Br09LDQ%3D%3D) | 25
R2 | 330 | R_0603_1608Metric | CR0603-FX-3300ELF | 652-CR0603FX-3300ELF (https://www.mouser.de/ProductDetail/Bourns/CR0603-FX-3300ELF?qs=I4suiNu8FYB0EfszDEV%252BGw%3D%3D) | 5
D1, D2, D3, D4, D5, D6, D7, D8, D9, D10, D11, D12, D13, D14, D15, D16, D17 | D_Small | D_0603_1608Metric | RB521S30T5G | 863-RB521S30T5G (https://www.mouser.de/ProductDetail/onsemi/RB521S30T5G?qs=M3GgpExcU2%2FPpNUGuFHiAQ%3D%3D) | 85
U1, U2, U3, U4, U5, U6, U7, U9, U10, U11, U12, U13, U14, U17, U21, U22 | Multi_Hotswap_with_RGB | Multi Hotswap with RGB 1U | - | - | 80
U8, U15 | Multi_Hotswap_with_RGB | Multi Hotswap with RGB 2U 90deg | - | - | 10
U16 | Multi_Hotswap_with_RGB | Multi Hotswap with RGB 2U | - | - | 5
U18 | ATmega328PB-A | TQFP-32_7x7mm_P0.8mm | ATMEGA328PB-AU | 556-ATMEGA328PB-AU (https://www.mouser.de/ProductDetail/Microchip-Technology/ATMEGA328PB-AU?qs=jy4bLUHv09hbFONgGrqPbw%3D%3D) | 5
U19 | ~ | SN74LVC2G17DCKR | SN74LVC2G17DCKR | 595-SN74LVC2G17DCKR (https://www.mouser.de/ProductDetail/Texas-Instruments/SN74LVC2G17DCKR?qs=spW5eSrOWB6kZFcYtrLxUQ%3D%3D) | 5
U20 | ~ | Alps EC12 with Neopixel | EC12E1220301 | 688-EC12E1220301 (https://www.mouser.de/ProductDetail/Alps-Alpine/EC12E1220301?qs=vrbHPQ%2FMREheAaIS%252B1GULw%3D%3D) | 5
Y1 | ABLS-16.000MHZ-D-3-Y-T | Crystal_SMD_HC49-SD | ABLS-16.000MHZ-D-3-Y-T | 815-ABLS16000MHZD3YT (https://www.mouser.de/ProductDetail/ABRACON/ABLS-16.000MHZ-D-3-Y-T?qs=vLWxofP3U2x0HoNFXNNNMA%3D%3D) | 5
RV1, RV2 | PTA6043-2010CIB502 | Potentiometer_Bourns_PTA6043_Single_Slide | PTA6043-2010CIB502 | 652-PTA6432010CIB502 (https://www.mouser.de/ProductDetail/Bourns/PTA6043-2010CIB502?qs=h2IHEVivlqD8b%252BPT0NYs%2Fw%3D%3D) | 10
J4, J5, J6, J7 | Conn_01x04 | POGO Magnetic 4 Pin 2,2mm Horizontal | - | - | 20
J1 | Display 1 | MC096VX and SSD1306 Display module 0.96” | - | - | 5
J2 | AVR-ISP-6 | Tag-Connect_TC2030-IDC-NL_2x03_P1.27mm_Vertical | - | - | 5
J3 | Display 2 | MC096VX and SSD1306 Display module 0.96” | - | - | 5

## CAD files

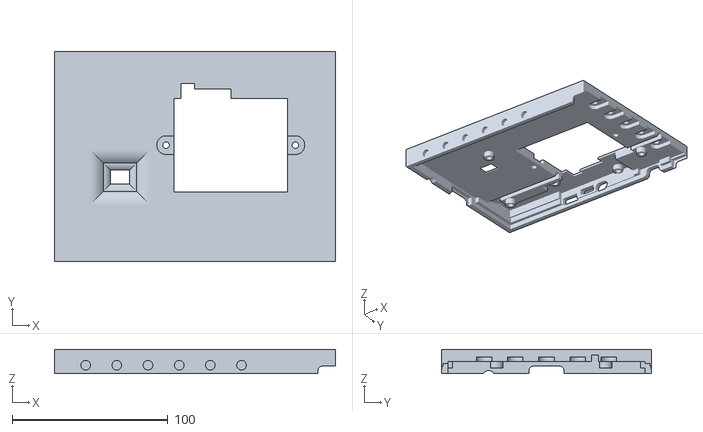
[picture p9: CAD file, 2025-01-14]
03 3D Files/Typeuwu Case/STL/Base 1.STL
180.3 x 134.6 x 15.6

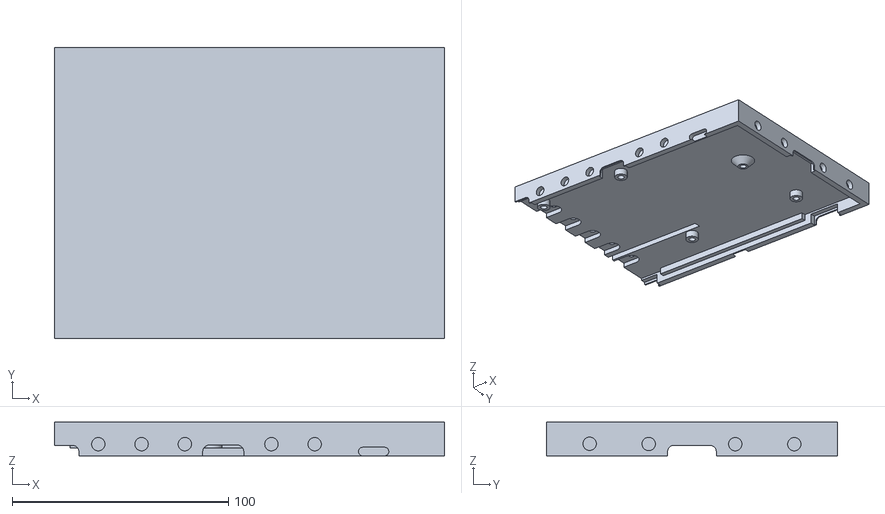
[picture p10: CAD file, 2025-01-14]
03 3D Files/Typeuwu Case/STL/Base 2.STL
180.2 x 134.6 x 15.6

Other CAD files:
03 3D Files/Modulu 1 Board/Modulu1.SLDASM
03 3D Files/Typeuwu Board/The Typeuwu.step.SLDASM
03 3D Files/Typeuwu Case/Case.SLDASM
01 PCB/01 The Typeuwu PCB/The Typeuwu.step
01 PCB/03 Numpad PCB/Numpad test 2.step
03 3D Files/Battery Board/Battery module.step
03 3D Files/Typeuwu Board/The Typeuwu.step
03 3D Files/Typeuwu Case/4-Pin Header - Female - 2.54mm.step
3D model/Typeuwu Case/Base 1.SLDPRT
01 PCB/03 Numpad PCB/Numpad.step
03 3D Files/Battery Board/Battery module 3.step
03 3D Files/Typeuwu Case/The Typeuwu.step
3D model/Typeuwu Case/Part2.SLDPRT
03 3D Files/Battery Board/Battery module 2.step
03 3D Files/Typeuwu Board/The Typeuwu-The Typeuwu.step
03 3D Files/Typeuwu Case/Display_OLED_0.96_128x64.step
01 PCB/02 Battery PCB/drawings/Battery-B_Silkscreen.dxf
01 PCB/02 Battery PCB/drawings/Battery-F_Silkscreen.dxf
01 PCB/03 Numpad PCB/Silkscreen/Numpad-B_Silkscreen.dxf
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

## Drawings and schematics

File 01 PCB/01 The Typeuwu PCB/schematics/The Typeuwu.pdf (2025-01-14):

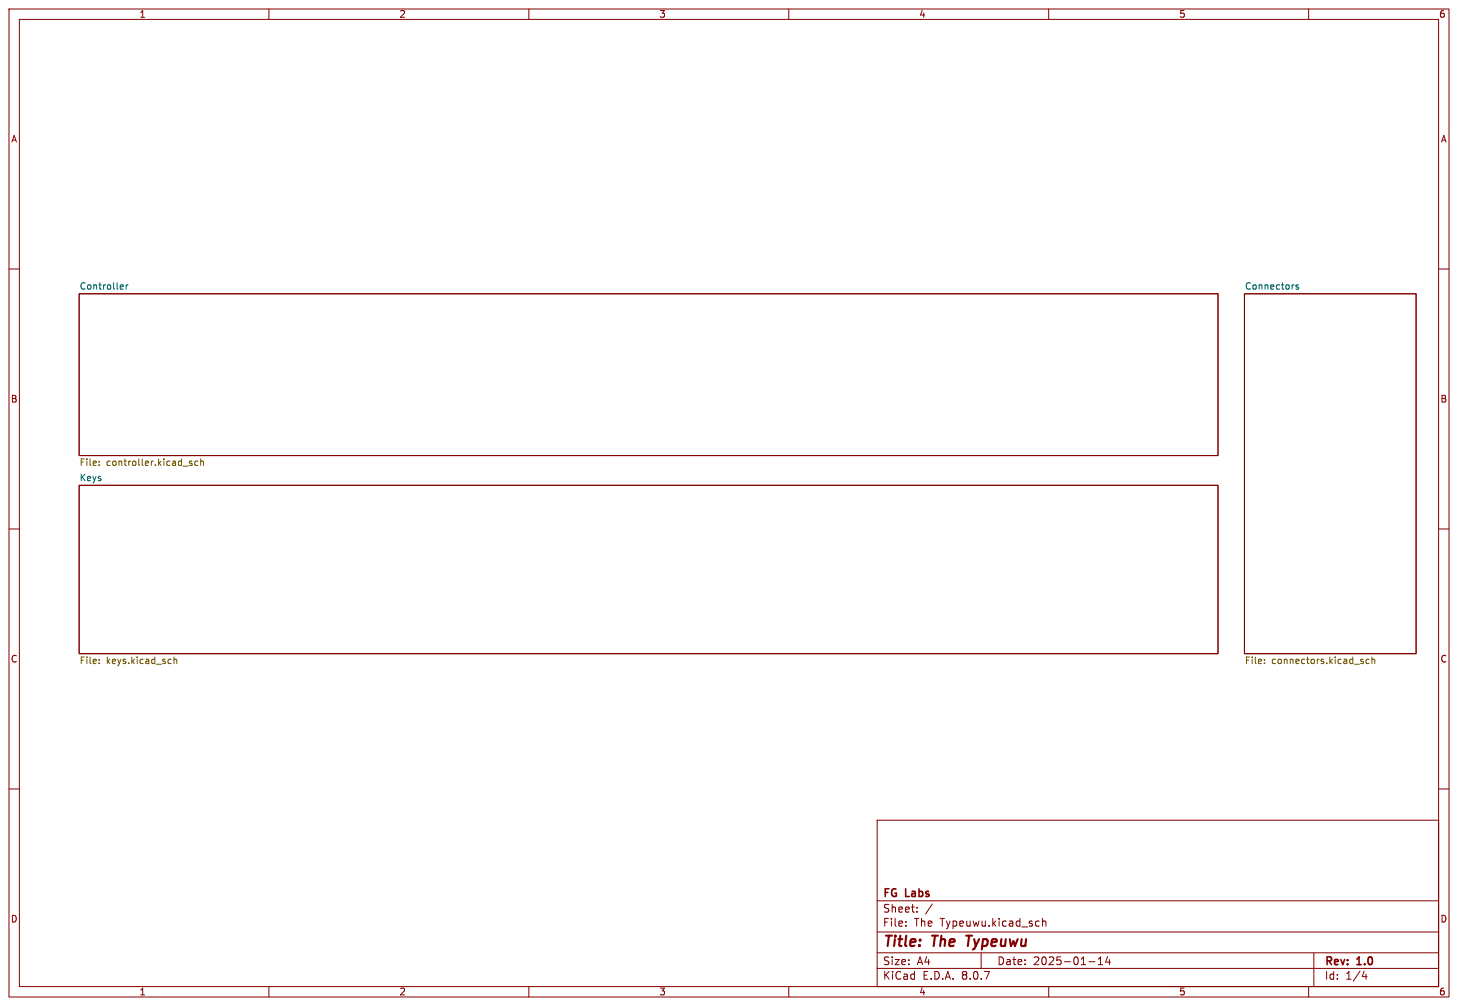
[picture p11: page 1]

Id: 1/4 Title: The Typeuwu

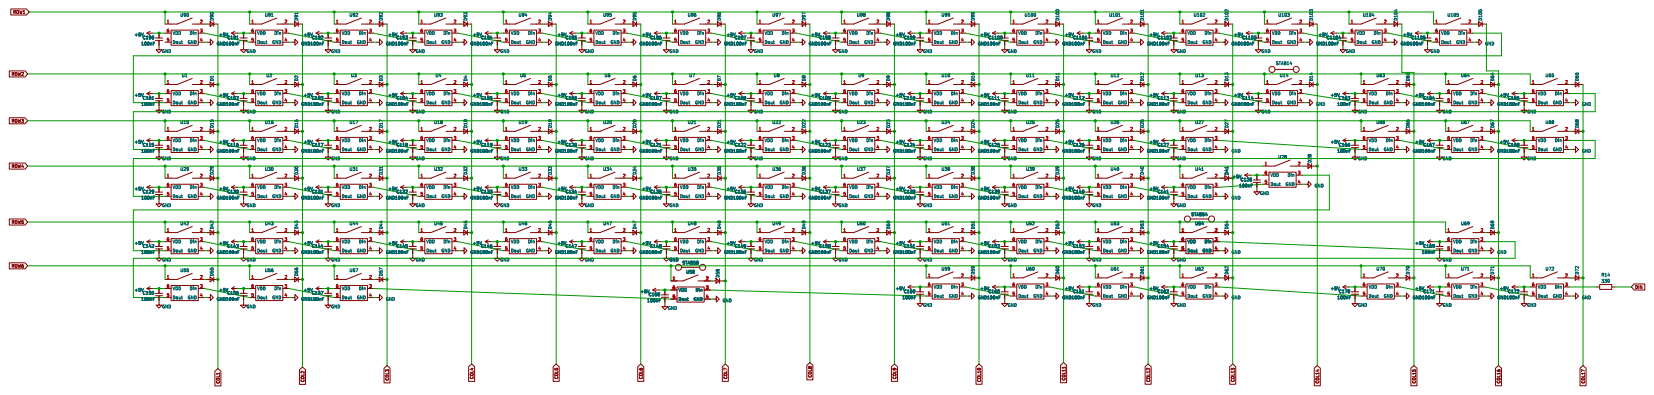
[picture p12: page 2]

File: keys.kicad_sch Sheet: /Keys/ FG Labs

Id: 2/4 Title: The Typeuwu

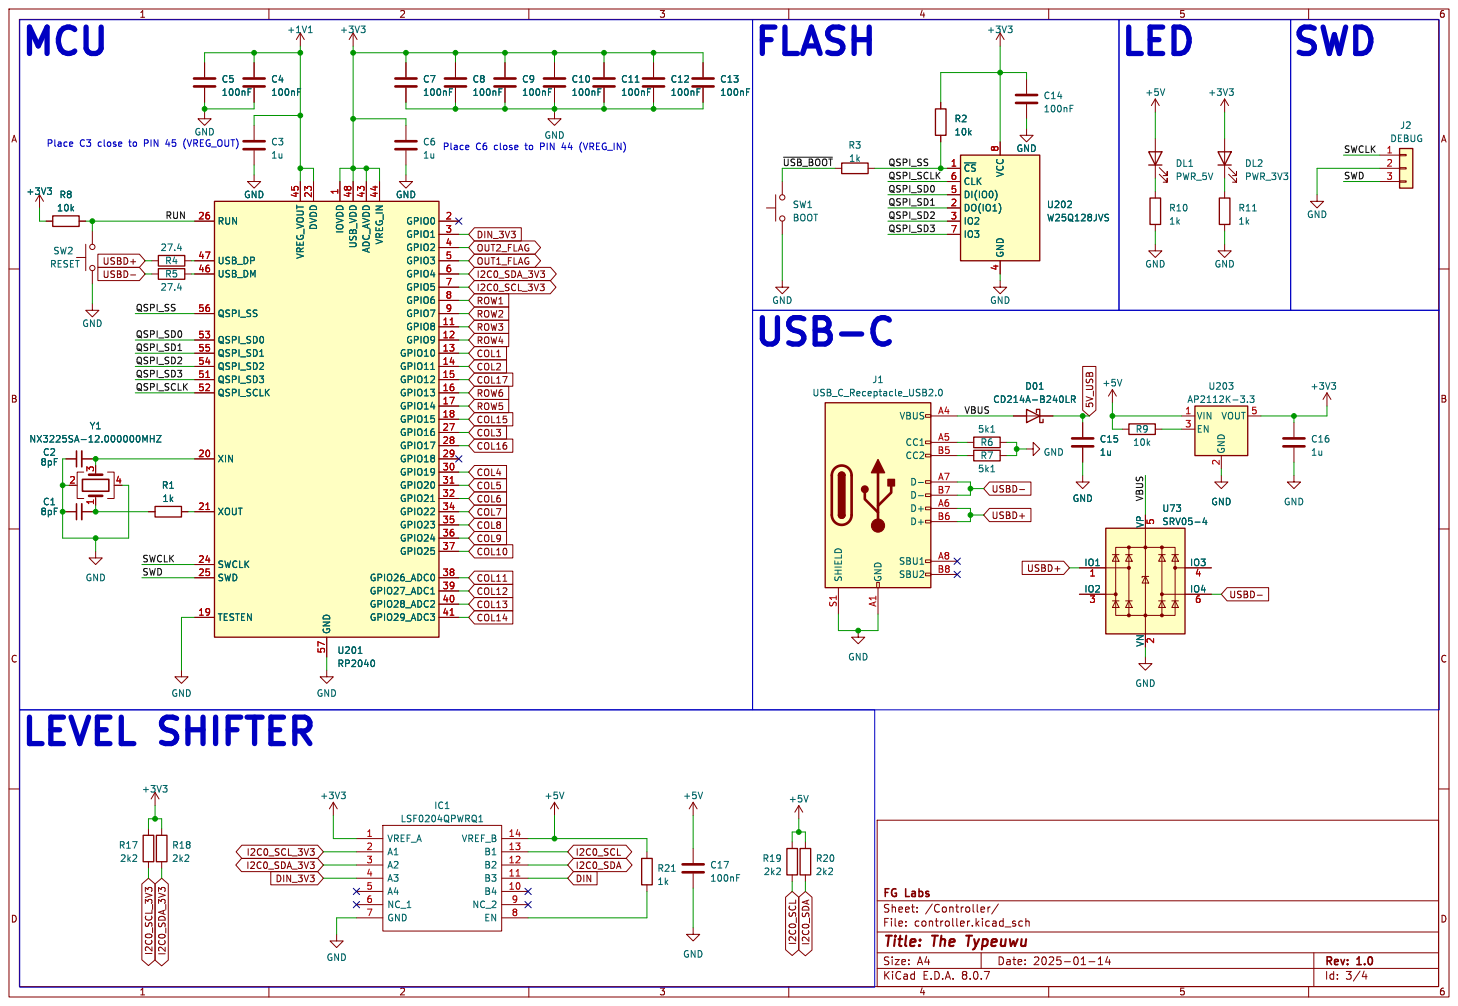
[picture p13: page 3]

Place C6 close to PIN 44 (VREG_IN) Place C3 close to PIN 45 (VREG_OUT)

1 GPIO8 11 GPIO9 12 GPIO10 13 GPIO11 14 GPIO12 15 GPIO13 16 GPIO14 17 GPIO15 18 TESTEN 19 GPIO0 2 XIN 20 XOUT 21 DVDD 23 SWCLK 24 SWD 25 RUN 26 GPIO16 27 GPIO17 28 GPIO18 29 GPIO1 3 GPIO19 30 GPIO20 31 GPIO21 32 GPIO22 34 GPIO23 35 GPIO24 36 GPIO25 37 GPIO26_ADC0 38 GPIO27_ADC1 39 GPIO2 4 GPIO28_ADC2 40 GPIO29_ADC3 41 ADC_AVDD 43 VREG_IN 44 VREG_VOUT 45 USB_DM 46 USB_DP 47 USB_VDD 48 GPIO3 5 QSPI_SD3 51 QSPI_SCLK 52 QSPI_SD0 53 QSPI_SD2 54 QSPI_SD1 55 QSPI_SS 56 GND 57 GPIO4 6 GPIO5 7 GPIO6 8 GPIO7 9 C2

1 GPIO8 11 GPIO9 12 GPIO10 13 GPIO11 14 GPIO12 15 GPIO13 16 GPIO14 17 GPIO15 18 TESTEN 19 GPIO0 2 XIN 20 XOUT 21 DVDD 23 SWCLK 24 SWD 25 RUN 26 GPIO16 27 GPIO17 28 GPIO18 29 GPIO1 3 GPIO19 30 GPIO20 31 GPIO21 32 GPIO22 34 GPIO23 35 GPIO24 36 GPIO25 37 GPIO26_ADC0 38 GPIO27_ADC1 39 GPIO2 4 GPIO28_ADC2 40 GPIO29_ADC3 41 ADC_AVDD 43 VREG_IN 44 VREG_VOUT 45 USB_DM 46 USB_DP 47 USB_VDD 48 GPIO3 5 QSPI_SD3 51 QSPI_SCLK 52 QSPI_SD0 53 QSPI_SD2 54 QSPI_SD1 55 QSPI_SS 56 GND 57 GPIO4 6 GPIO5 7 GPIO6 8 GPIO7 9 U201 RP2040 GND

Id: 3/4 Title: The Typeuwu

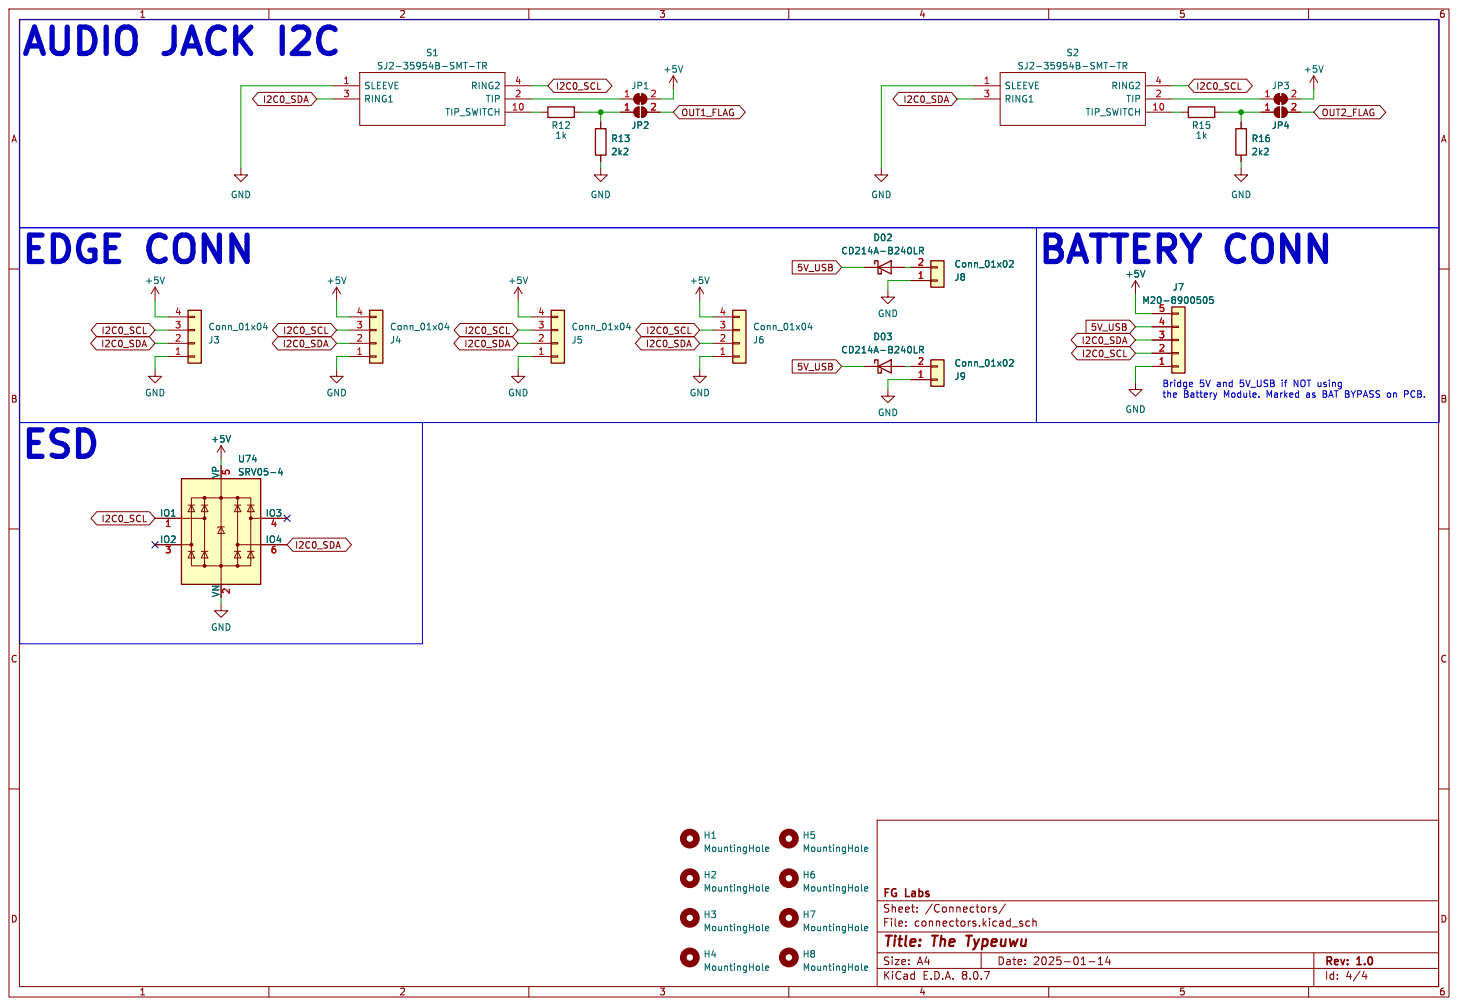
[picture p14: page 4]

the Battery Module. Marked as BAT BYPASS on PCB. AUDIO JACK I2C

Bridge 5V and 5V_USB if NOT using

Id: 4/4 Title: The Typeuwu

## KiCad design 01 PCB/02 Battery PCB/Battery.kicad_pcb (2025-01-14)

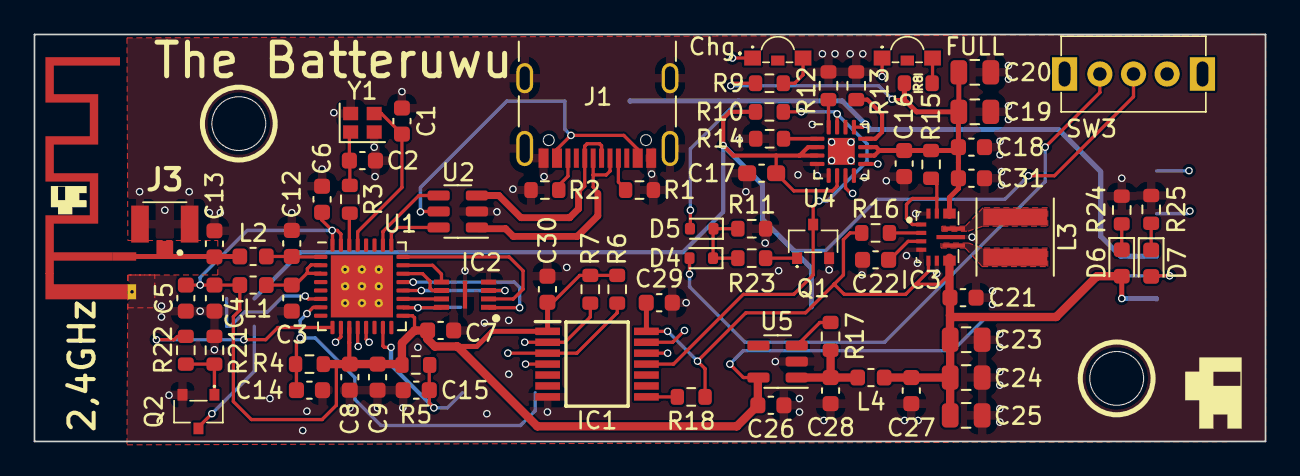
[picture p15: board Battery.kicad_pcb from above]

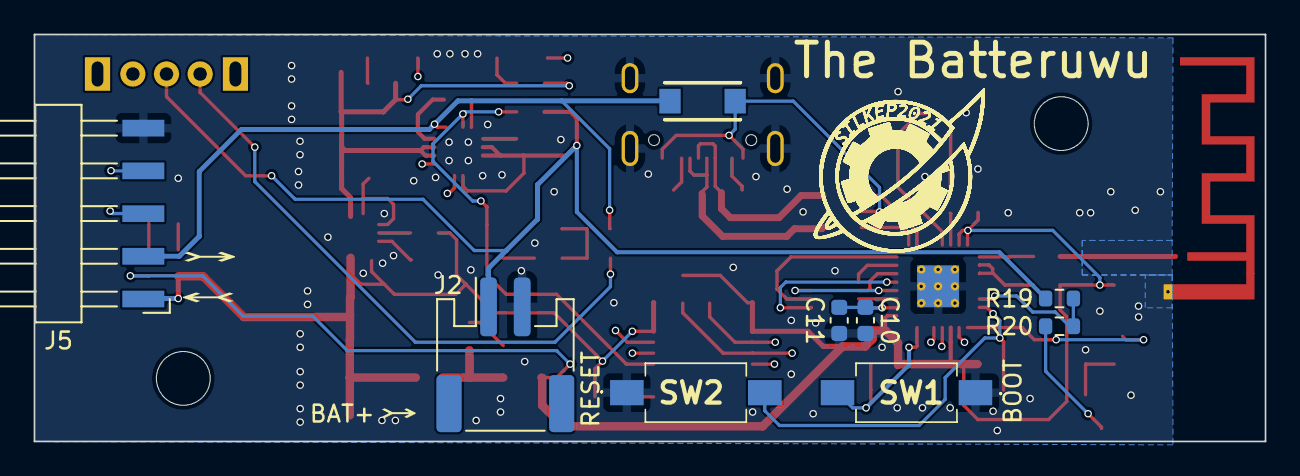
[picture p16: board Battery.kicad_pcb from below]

Board: 4 copper layers, 73.2 x 24.2 mm, 87 parts (9 on the bottom side), 58 nets.

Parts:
C1, C2: 10p; C_0603_1608Metric
C3, C4, C6, C7, C8, C11, C14, C15, C22, C27, C28, C29, C30, C31: 100n; C_0603_1608Metric
C5, C9, C10: 10u; C_0603_1608Metric
C12, C13: 3p3; C_0603_1608Metric
C16: 4.7 uF; C_0603_1608Metric
C17: 4.7 uF; C_0603_1608Metric_Pad1.08x0.95mm_HandSolder
C18, C21: 10uF; C_0603_1608Metric
C19, C20: 10uF; C_0805_2012Metric
C23, C24, C25: 22uF; C_0805_2012Metric
C26: 1u; C_0603_1608Metric
D1: CD214A-B240LR
D2: LED green; 155124RS73200
D3: LED red; 155124RS73200
D4, D5: RB21S30T5G; D_SOD-523
D6, D7: LED; LED_0603_1608Metric
H1, H2: MountingHole; MountingHole_3.2mm_M3_DIN965
IC1: LSF0204QPWRQ1; SOP65P640X120-14N
IC2: W25Q16JVUXIQ_TR; SON50P300X200X60-9N
IC3: TPS630701RNMR
J1: USB_C_Receptacle_USB2.0; USB_C_Receptacle_GCT_USB4105-xx-A_16P_TopMnt_Horizontal
J2: BATTERY; JST_PH_S2B-PH-SM4-TB_1x02-1MP_P2.00mm_Horizontal
J3: 2337019-1; 23370191
J5: M20-8900505; Harwin_M20-89005xx_1x05_P2.54mm_Horizontal
L1, L2, L4: 2n2; L_0603_1608Metric
L3: 1.5uH; EATON_EXL1V0402_4.6mmx4.6mm
Q1, Q2: T2N7002AK,LM; TBAT54CLM
R1, R2, R4, R5, R6, R7, R10: 5k1; R_0603_1608Metric
R3: 22; R_0603_1608Metric
R8, R9: 510; R_0603_1608Metric
R11, R14, R15, R17, R19, R21: 10k; R_0603_1608Metric
R12, R13: 1.18k; R_0603_1608Metric
R16: 100k; R_0603_1608Metric
R18, R22, R23, R24, R25: 1k; R_0603_1608Metric
R20: 22k; R_0603_1608Metric
SW1, SW2: PTS636 SP50; PTS636SP50SMTRLFS
SW3: POWER SWITCH; SLW-864547-5A-RA-D
U1: ESP32C3; QFN-32-1EP_5x5mm_P0.5mm_EP3.7x3.7mm_ThermalVias
U2: USBLC6-2SC6; SOT-23-6
U3: 2.4GHZ_PCB_Antenna_AN043; 2.4GHZ PCB Antenna AN043
U4: BQ24075RGT; VQFN-16-1EP_3x3mm_P0.5mm_EP1.6x1.6mm
U5: AP2112K-3.3; SOT-23-5
Y1: ECS-400-10-37B2-CKM-TR; Crystal_SMD_2016-4Pin_2.0x1.6mm

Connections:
5V CHRG: D1.1 (K), D5.2 (A), J5.2, U4.13 (IN)
+3V3: C4.1, C5.1, C6.1, C7.1, C8.1, C9.1, C26.1, C30.1, D7.2 (A), IC1.1 (VREF_A), L1.2, R4.2, R5.2, R6.2, R7.2, U1.11 (VDD3P3_RTC), U1.17 (VDD3P3_CPU), U1.31 (VDDA), U1.32 (VDDA), U5.5 (VOUT)
+5V: C21.1, C23.1, C24.1, C25.1, C27.1, C29.1, D6.2 (A), IC1.14 (VREF_B), IC3.5 (FB), IC3.7 (VOUT_1), IC3.8 (VOUT_2), J5.1, L4.1, R16.1, R18.1
/Power/CHG: D3.1 (K), U4.9 (~CHG)
/Power/DPPM OUT: C16.1, C18.1, C19.1, C20.1, C31.1, IC3.12 (VIN_1), IC3.13 (VIN_2), R8.1, R9.1, R15.1, U4.10 (OUT), U4.11 (OUT)
/Power/PGOOD: D2.1 (K), U4.7 (~PGOOD)
/Wireless/3V3 RF: C3.1, L1.1, U1.2 (VDD3P3), U1.3 (VDD3P3)
/Wireless/ANT_RF: C13.1, J3.1 (SIGNAL), L2.2, U3.1
/Wireless/BOOT: C15.1, R5.1, SW1.2, U1.15 (GPIO9)
/Wireless/CC1: J1.A5 (CC1), R1.1
/Wireless/CC2: J1.B5 (CC2), R2.1
/Wireless/EN_LS: IC1.8 (EN), R18.2
/Wireless/MCU_LNA: C12.1, L2.1, U1.1 (LNA_IN)
/Wireless/RESET: C14.1, R4.1, SW2.2, U1.7 (CHIP_EN)
/Wireless/VUSB: D1.2 (A), J1.A4 (VBUS), J1.A9 (VBUS), J1.B4 (VBUS), J1.B9 (VBUS), U2.5 (VBUS)
/Wireless/XTAL_N: C1.1, U1.29 (XTAL_N), Y1.3
/Wireless/XTAL_P: R3.1, U1.30 (XTAL_P)
/Wireless/XTAL_P_R: C2.1, R3.2, Y1.1
BAT+: C17.1, J2.1, R10.2, R19.1, SW3.2 (B), U4.2 (BAT), U4.3 (BAT), U4.6 (EN1)
ESP_DISABLE: IC1.4 (A3), U1.10 (MTDI)
GND: C1.2, C2.2, C3.2, C4.2, C5.2, C6.2, C7.2, C8.2, C9.2, C10.2, C11.2, C12.2, C13.2, C14.2, C15.2, C16.2, C17.2, C18.2, C19.2, C20.2, C21.2, C22.2, C23.2, C24.2, C25.2, C26.2, C27.2, C28.2, C29.2, C30.2, C31.2, IC1.7 (GND), IC2.4 (GND), IC2.9 (EP), IC3.4 (GND), IC3.6 (FB2), IC3.10 (PGND), IC3.15 (VSEL), J1.A1 (GND), J1.A12 (GND), J1.B1 (GND), J1.B12 (GND), J1.S1 (SHIELD), J2.2, J3.2 (GND_1), J3.3 (GND_2), J5.5, Q1.2 (S), Q2.2 (S), R1.2, R2.2, R11.2, R12.2, R13.2, R14.2, R21.2, R24.2, R25.2, SW1.1, SW2.1, U1.33 (EP), U2.2 (GND), U3.2, U4.4 (~CE), U4.5 (EN2), U4.8 (VSS), U4.17 (VSS), U5.2 (GND), Y1.2, Y1.4
MCU_D+: U1.26 (GPIO19), U2.4 (I/O2)
MCU_D-: U1.25 (GPIO18), U2.6 (I/O1)
unnamed: D2.2 (A), R8.2
unnamed: D3.2 (A), R9.2
unnamed: D4.2 (A), SW3.1 (A)
unnamed: D4.1 (K), D5.1 (K), R11.1, R23.1
unnamed: D6.1 (K), R24.1
unnamed: D7.1 (K), R25.1
unnamed: IC3.1 (PS/S), IC3.14 (EN), R15.2
unnamed: IC3.11 (L1), L3.1
unnamed: IC3.9 (L2), L3.2
unnamed: IC3.2 (PG), R16.2
unnamed: C22.1, IC3.3 (VAUX)
unnamed: Q1.1 (G), R23.2
unnamed: Q2.3 (D), R20.2
unnamed: Q2.1 (G), R21.1, R22.2
unnamed: R13.1, U4.12 (ILIM)
unnamed: R12.1, U4.16 (ISET)
unnamed: R17.2, U5.3 (EN)
unnamed: C28.1, L4.2, R17.1, U5.1 (VIN)
SCL_3V3: IC1.2 (A1), R7.1, U1.13 (MTDO)
SCL_5V: IC1.13 (B1), J5.4
SDA_3V3: IC1.3 (A2), R6.1, U1.12 (MTCK)
SDA_5V: IC1.12 (B2), J5.3
SPI_CLK: IC2.6 (CLK), U1.22 (SPICLK)
SPI_CS: IC2.1 (~CS), U1.21 (SPICS0)
SPI_DI: IC2.5 (DI(IO0)), U1.23 (SPID)
SPI_DO: IC2.2 (DO(IO1)), U1.24 (SPIQ)
SPI_HOLD: IC2.7 (IO3), U1.19 (SPIHD)
SPI_WP: IC2.3 (IO2), U1.20 (SPIWP)
SYSOFF: IC1.11 (B3), Q1.3 (D), R10.1, U4.15 (SYSOFF)
TS: R14.1, U4.1 (TS)
USB_D+: J1.A6 (D+), J1.B6 (D+), U2.3 (I/O2)
USB_D-: J1.A7 (D-), J1.B7 (D-), U2.1 (I/O1)
VDD SPI: C10.1, C11.1, IC2.8 (VCC), U1.18 (VDD_SPI)
V_SENSE: R19.2, R20.1, U1.6 (GPIO2)
V_SENSE_EN: R22.1, U1.9 (MTMS)

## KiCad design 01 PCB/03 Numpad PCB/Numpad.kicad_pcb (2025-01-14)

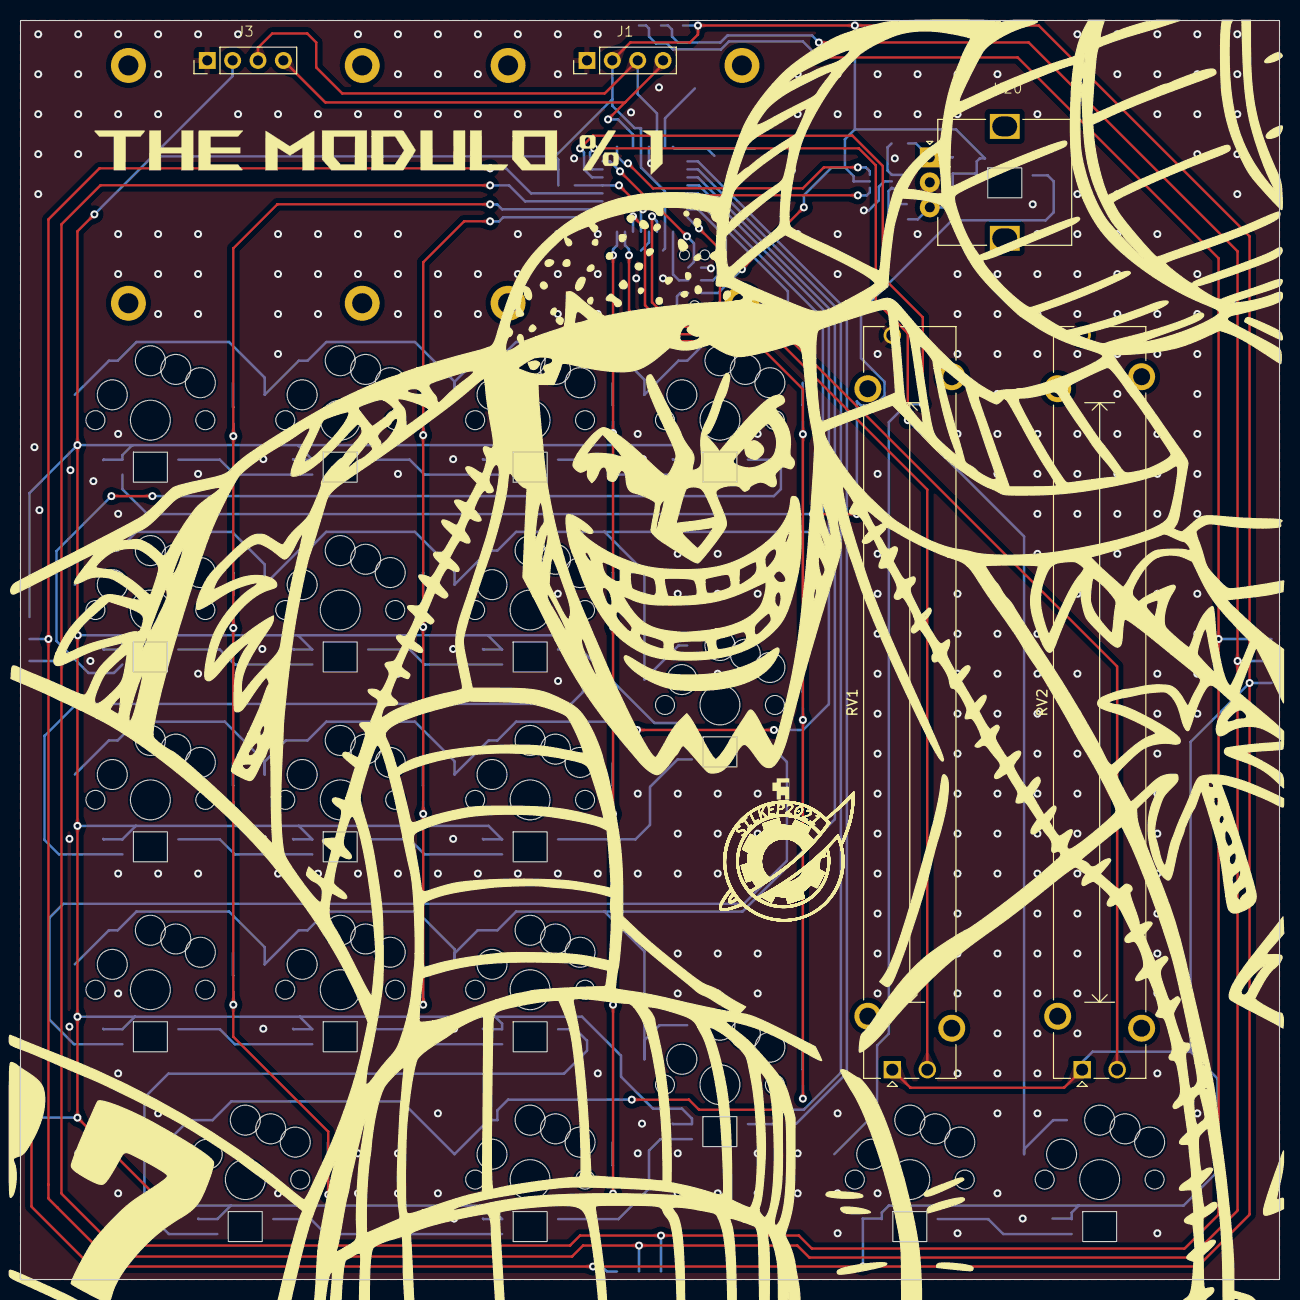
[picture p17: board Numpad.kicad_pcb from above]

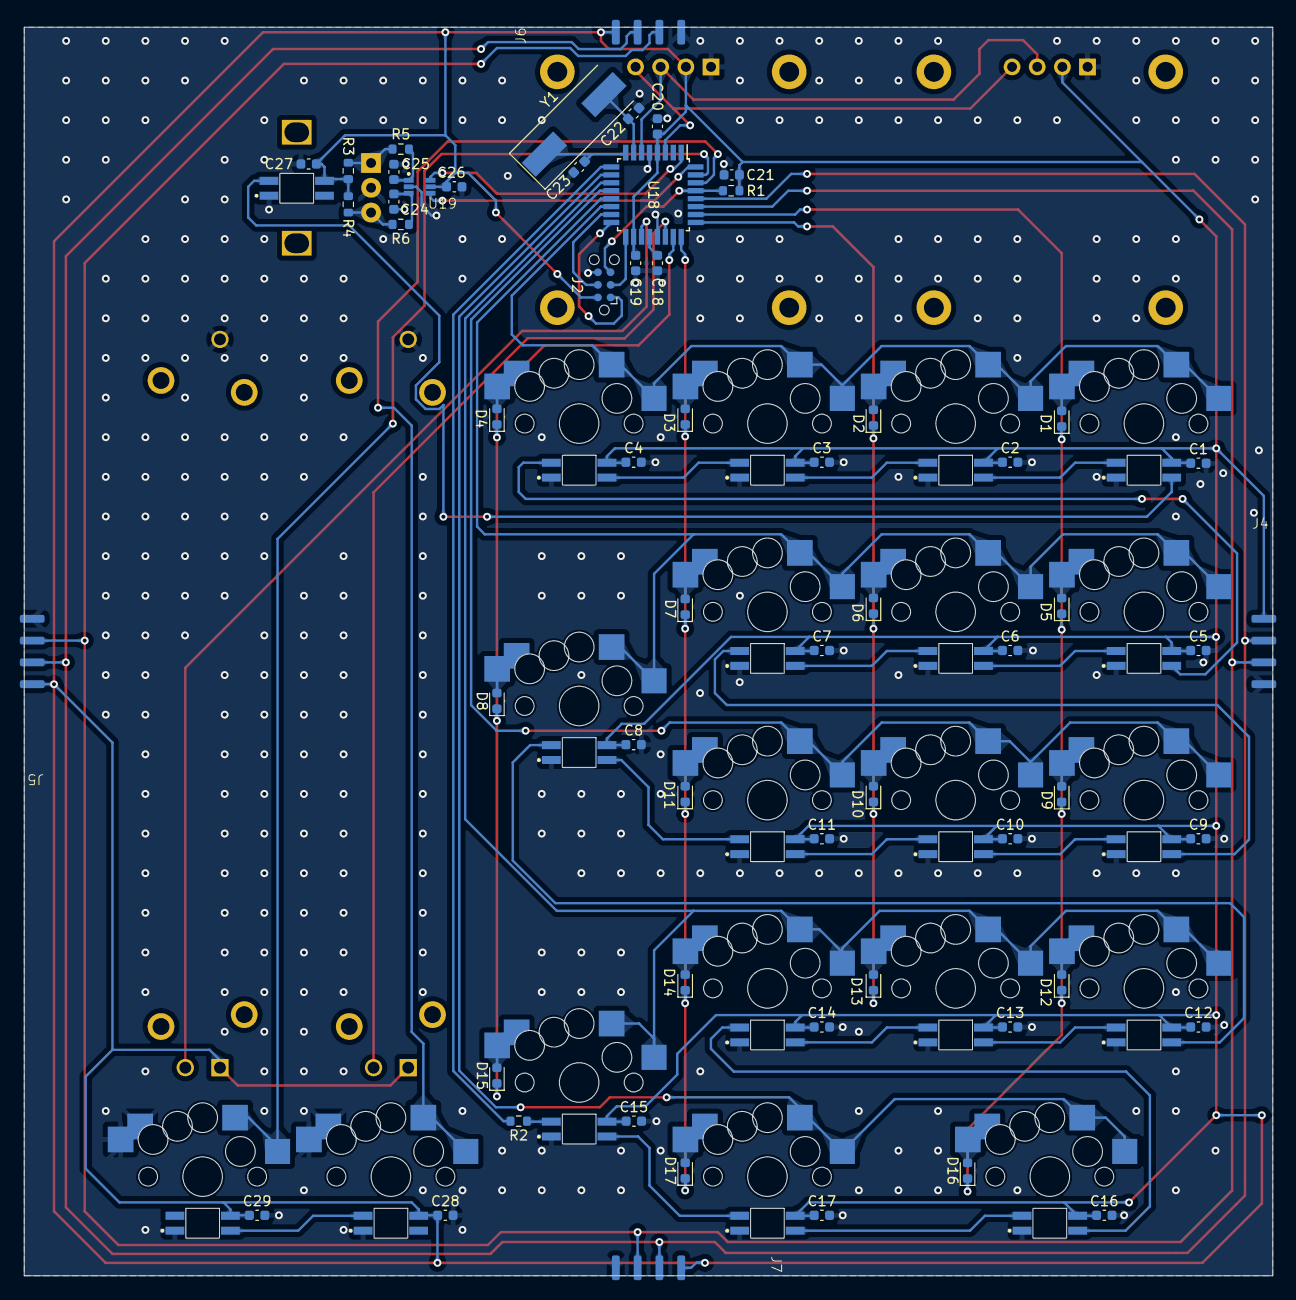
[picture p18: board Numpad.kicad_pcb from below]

Board: 2 copper layers, 126.0 x 126.0 mm, 84 parts (60 on the bottom side), 69 nets.

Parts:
C1, C2, C3, C4, C5, C6, C7, C8, C9, C10, C11, C12, C13, C14, C15, C16, C17, C18, C19, C20, C24, C25, C26, C27, C28, C29: 100nF; C_0603_1608Metric
C21: 1uF; C_0603_1608Metric
C22, C23: 22pF; C_0603_1608Metric
D1, D2, D3, D4, D5, D6, D7, D8, D9, D10, D11, D12, D13, D14, D15, D16, D17: D_Small; D_0603_1608Metric
J1: Display 1; MC096VX and SSD1306 Display module 0.96”
J2: AVR-ISP-6; Tag-Connect_TC2030-IDC-NL_2x03_P1.27mm_Vertical
J3: Display 2; MC096VX and SSD1306 Display module 0.96”
J4, J5, J6, J7: Conn_01x04; POGO Magnetic 4 Pin 2,2mm Horizontal
R1, R3, R4, R5, R6: 10k; R_0603_1608Metric
R2: 330; R_0603_1608Metric
RV1, RV2: PTA6043-2010CIB502; Potentiometer_Bourns_PTA6043_Single_Slide
U1, U2, U3, U4, U5, U6, U7, U9, U10, U11, U12, U13, U14, U17, U21, U22: Multi_Hotswap_with_RGB; Multi Hotswap with RGB 1U
U8, U15: Multi_Hotswap_with_RGB; Multi Hotswap with RGB 2U 90deg
U16: Multi_Hotswap_with_RGB; Multi Hotswap with RGB 2U
U18: ATmega328PB-A; TQFP-32_7x7mm_P0.8mm
U19: SN74LVC2G17DCKR
U20: Alps EC12 with Neopixel
Y1: ABLS-16.000MHZ-D-3-Y-T; Crystal_SMD_HC49-SD

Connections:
+5V: C1.1, C2.1, C3.1, C4.1, C5.1, C6.1, C7.1, C8.1, C9.1, C10.1, C11.1, C12.1, C13.1, C14.1, C15.1, C16.1, C17.1, C19.1, C20.1, C21.1, C26.1, C27.1, C28.1, C29.1, J1.2, J2.2 (VCC), J3.2, J4.4, J5.4, J6.4, J7.4, R1.1, R3.1, R4.1, RV1.1, RV2.1, U1.6 (VDD), U2.6 (VDD), U3.6 (VDD), U4.6 (VDD), U5.6 (VDD), U6.6 (VDD), U7.6 (VDD), U8.6 (VDD), U9.6 (VDD), U10.6 (VDD), U11.6 (VDD), U12.6 (VDD), U13.6 (VDD), U14.6 (VDD), U15.6 (VDD), U16.6 (VDD), U17.6 (VDD), U18.4 (VCC), U18.18 (AVCC), U19.5 (VCC), U20.4 (VDD), U21.6 (VDD), U22.6 (VDD)
COL_1: D1.1 (K), D5.1 (K), D9.1 (K), D12.1 (K), D16.1 (K), U18.26 (PC3)
COL_2: D2.1 (K), D6.1 (K), D10.1 (K), D13.1 (K), U18.25 (PC2)
COL_3: D3.1 (K), D7.1 (K), D11.1 (K), D14.1 (K), D17.1 (K), U18.24 (PC1)
COL_4: D4.1 (K), D8.1 (K), D15.1 (K), U18.23 (PC0)
DIN: R2.2, U18.9 (PD5)
DOUT_ENCODER: U1.5 (Dout), U20.1 (Din)
GND: C1.2, C2.2, C3.2, C4.2, C5.2, C6.2, C7.2, C8.2, C9.2, C10.2, C11.2, C12.2, C13.2, C14.2, C15.2, C16.2, C17.2, C18.2, C19.2, C20.2, C21.2, C22.2, C23.2, C24.2, C25.2, C26.2, C27.2, C28.2, C29.2, J1.1, J2.6 (GND), J3.1, J4.1, J5.1, J6.1, J7.1, RV1.3, RV2.3, U1.4 (GND), U2.4 (GND), U3.4 (GND), U4.4 (GND), U5.4 (GND), U6.4 (GND), U7.4 (GND), U8.4 (GND), U9.4 (GND), U10.4 (GND), U11.4 (GND), U12.4 (GND), U13.4 (GND), U14.4 (GND), U15.4 (GND), U16.4 (GND), U17.4 (GND), U18.5 (GND), U18.21 (GND), U19.2 (GND), U20.2 (GND), U20.C, U21.2, U21.4 (GND), U22.2, U22.4 (GND)
INT_0: U18.32 (PD2), U19.4 (2Y)
INT_1: U18.1 (PD3), U19.6 (1Y)
MISO: J2.1 (MISO), U18.16 (PB4)
MOSI: J2.4 (MOSI), U18.15 (PB3)
unnamed: D1.2 (A), U1.2
unnamed: D2.2 (A), U2.2
unnamed: D3.2 (A), U3.2
unnamed: D4.2 (A), U4.2
unnamed: D5.2 (A), U5.2
unnamed: D6.2 (A), U6.2
unnamed: D7.2 (A), U7.2
unnamed: D8.2 (A), U8.2
unnamed: D9.2 (A), U9.2
unnamed: D10.2 (A), U10.2
unnamed: D11.2 (A), U11.2
unnamed: D12.2 (A), U12.2
unnamed: D13.2 (A), U13.2
unnamed: D14.2 (A), U14.2
unnamed: D15.2 (A), U15.2
unnamed: D16.2 (A), U16.2
unnamed: D17.2 (A), U17.2
unnamed: R3.2, R5.2, U20.A
unnamed: R4.2, R6.2, U20.B
unnamed: U1.3 (Din), U2.5 (Dout)
unnamed: U2.3 (Din), U3.5 (Dout)
unnamed: U3.3 (Din), U4.5 (Dout)
unnamed: U4.3 (Din), U5.5 (Dout)
unnamed: U5.3 (Din), U6.5 (Dout)
unnamed: U6.3 (Din), U7.5 (Dout)
unnamed: U7.3 (Din), U9.5 (Dout)
unnamed: U10.3 (Din), U11.5 (Dout)
unnamed: U9.3 (Din), U10.5 (Dout)
unnamed: U8.5 (Dout), U11.3 (Din)
unnamed: U12.3 (Din), U13.5 (Dout)
unnamed: U8.3 (Din), U12.5 (Dout)
unnamed: U13.3 (Din), U14.5 (Dout)
unnamed: U14.3 (Din), U16.5 (Dout)
unnamed: R2.1, U15.3 (Din)
unnamed: U15.5 (Dout), U17.3 (Din)
unnamed: U16.3 (Din), U17.5 (Dout)
unnamed: C18.1, U18.20 (AREF)
unnamed: C25.1, R5.1, U19.1 (1A)
unnamed: C24.1, R6.1, U19.3 (2A)
unnamed: U21.3 (Din), U22.5 (Dout)
RESET: J2.5 (~RST), R1.2, U18.29 (~RESET/PC6)
ROW_1: U1.1, U2.1, U3.1, U4.1, U18.14 (PB2)
ROW_2: U5.1, U6.1, U7.1, U8.1, U18.13 (PB1)
ROW_3: U9.1, U10.1, U11.1, U18.12 (PB0)
ROW_4: U12.1, U13.1, U14.1, U15.1, U18.11 (PD7)
ROW_5: U16.1, U17.1, U18.10 (PD6)
SCK: J2.3 (SCK), U18.17 (PB5)
SCL_0: J4.3, J5.3, J6.3, J7.3, U18.28 (PC5)
SCL_1: J1.3, J3.3, U18.6 (PE1)
SDA_0: J4.2, J5.2, J6.2, J7.2, U18.27 (PC4)
SDA_1: J1.4, J3.4, U18.3 (PE0)
SLIDER_BUTTON_1: U18.30 (PD0), U21.1
SLIDER_BUTTON_2: U18.31 (PD1), U22.1
Slider_1: RV1.2, U18.22 (PE3)
Slider_2: RV2.2, U18.19 (PE2)
XTAL1: C22.1, U18.7 (XTAL1/PB6), Y1.2
XTAL2: C23.1, U18.8 (XTAL2/PB7), Y1.1

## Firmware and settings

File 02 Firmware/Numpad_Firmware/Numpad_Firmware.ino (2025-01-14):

#include "Wire.h"
#include <Adafruit_NeoPixel.h>

#define MODULE_ADDRESS 0x20
#define I2C_BUFFER_SIZE 32

#define KEY_REMAPPING \
{ 1,  2,  3,  4},\
{ 5,  6,  7,  8},\
{ 9, 10, 11,  0},\
{12, 13, 14, 15},\
{16,  0, 17,  0},\

#define AMMOUNT_ROW 5
#define ROW1 10
#define ROW2 9
#define ROW3 8
#define ROW4 7
#define ROW5 6

#define AMMOUNT_COL 4
#define COL1 17
#define COL2 16
#define COL3 15
#define COL4 14

//--------ANALOG------------

#define PIN_SLIDER_BUTTON_1 0
#define PIN_SLIDER_BUTTON_2 1

#define PIN_SLIDER_1 26
#define PIN_SLIDER_2 25

#define ANALOG_DB 2
#define ADDITIONAL_ANALOG_ZERO_OFFSET 4

uint8_t slider1 = 0;
uint8_t slider2 = 0;

#define AMMOUNT_KEYS 23

int pins_row[AMMOUNT_ROW] = {ROW1, ROW2, ROW3, ROW4, ROW5};
int pins_col[AMMOUNT_COL] = {COL1, COL2, COL3, COL4};
uint8_t pressed[AMMOUNT_KEYS];

int diodeMatrixToKeyIndex[AMMOUNT_ROW][AMMOUNT_COL] = {KEY_REMAPPING};


#define IDLE 0x10
#define SEND_STATES 0x11

uint8_t mode = IDLE;

void receive_handler(int howMany);
void request_handler(void);

//------------------------Lighting-----------------------------
#define LED_PIN    5
#define LED_COUNT 23
#define LED_BRIGHTNESS 100

unsigned long pixelPrevious = 0;        // Previous Pixel Millis
unsigned long patternPrevious = 0;      // Previous Pattern Millis
int           patternCurrent = 0;       // Current Pattern Number
int           patternInterval = 5000;   // Pattern Interval (ms)
int           pixelInterval = 50;       // Pixel Interval (ms)
int           pixelQueue = 0;           // Pattern Pixel Queue
int           pixelCycle = 0;           // Pattern Pixel Cycle
uint16_t      pixelCurrent = 0;         // Pattern Current Pixel Number
uint16_t      pixelNumber = LED_COUNT;  // Total Number of Pixels

Adafruit_NeoPixel strip(LED_COUNT, LED_PIN, NEO_GRB + NEO_KHZ800);

void lightingSetup();
uint32_t Wheel(byte WheelPos);
void rainbow(uint8_t wait);

void setup() {
  delay(1000);
  pinMode(PIN_SLIDER_BUTTON_1, INPUT_PULLUP);
  pinMode(PIN_SLIDER_BUTTON_2, INPUT_PULLUP);

  Wire.begin(MODULE_ADDRESS);
  Wire.onRequest(request_handler);
  Wire.onReceive(receive_handler);
  //pinMode(A4, INPUT_PULLUP);
  //pinMode(A5, INPUT_PULLUP);
  lightingSetup();
  for(int i = 0; i < AMMOUNT_KEYS; i++){
    pressed[i] = 0;
  }
}

//int color = 255;

void loop() {
  update();
  rainbow(10);
  //if(!digitalRead(18)) strip.setPixelColor(1, strip.Color(255, 0, 0));
  //if(digitalRead(18)) strip.setPixelColor(1, strip.Color(0, 0, 0));
  //if(!digitalRead(19)) strip.setPixelColor(2, strip.Color(255, 0, 0));
  //if(digitalRead(19)) strip.setPixelColor(2, strip.Color(0, 0, 0));
  //strip.show();
  //strip.setPixelColor(10, strip.Color(0, map(analogRead(PIN_SLIDER_2), 0, 1023, 0, 255), 0));
  //strip.setPixelColor(1, strip.Color(0, color, 0));
  //color--;
  //if(color == 0) color = 255;
}

void update(){
  //Matrix
  for(int row = 0; row < AMMOUNT_ROW; row++){
    pinMode(pins_row[row], OUTPUT);
    delay(1);
    digitalWrite(pins_row[row], HIGH);
    delay(1);

    for(int col = AMMOUNT_COL - 1; col >= 0; col--){
      if(digitalRead(pins_col[col])){
        if(diodeMatrixToKeyIndex[row][col] != 0){
          pressed[diodeMatrixToKeyIndex[row][col] - 1] = 1;
        }
      }
      else{
        pressed[diodeMatrixToKeyIndex[row][col] - 1] = 0;
      }
    }
    delay(1);
    digitalWrite(pins_row[row], LOW);
    delay(1);
    pinMode(pins_row[row], INPUT);
    delay(1);
  }
  //Buttons slider
  pressed[17] = !digitalRead(PIN_SLIDER_BUTTON_1);
  pressed[18] = !digitalRead(PIN_SLIDER_BUTTON_2);

  //Slider
  if((map(analogRead(PIN_SLIDER_1), 0, 1023, 255, 0) >= (slider1 + ANALOG_DB)) || (map(analogRead(PIN_SLIDER_1), 0, 1023, 255, 0) <= (slider1 - ANALOG_DB))){
    slider1 = map(analogRead(PIN_SLIDER_1), 0, 1023, 255, 0);
  }
  if((map(analogRead(PIN_SLIDER_2), 0, 1023, 255, 0) >= (slider2 + ANALOG_DB)) || (map(analogRead(PIN_SLIDER_2), 0, 1023, 255, 0) <= (slider2 - ANALOG_DB))){
    slider2 = map(analogRead(PIN_SLIDER_2), 0, 1023, 255, 0);
  }
  
  if(map(analogRead(PIN_SLIDER_1), 0, 1023, 255, 0) < (ADDITIONAL_ANALOG_ZERO_OFFSET + ANALOG_DB)){
    slider1 = 0;
  }
  if(map(analogRead(PIN_SLIDER_2), 0, 1023, 255, 0) < (ADDITIONAL_ANALOG_ZERO_OFFSET + ANALOG_DB)){
    slider2 = 0;
  }

  if(map(analogRead(PIN_SLIDER_1), 0, 1023, 255, 0) > (255 - ADDITIONAL_ANALOG_ZERO_OFFSET + ANALOG_DB)){
    slider1 = 255;
  }
  if(map(analogRead(PIN_SLIDER_2), 0, 1023, 255, 0) > (255 - ADDITIONAL_ANALOG_ZERO_OFFSET + ANALOG_DB)){
    slider2 = 255;
  }
  pressed[19] = slider1;
  pressed[20] = slider2;
}

void receive_handler(int howMany){
  if(Wire.available()){
    mode = Wire.read();
  }
  if(mode == SEND_STATES) strip.setPixelColor(6, strip.Color(0, 255, 0));
  while(Wire.available()) Wire.read();
}

void request_handler(void){
  uint8_t i = 0;
  switch (mode) {
    case IDLE:
      //strip.setPixelColor(1, strip.Color(0, 255, 0));
      //strip.setPixelColor(2, strip.Color(0, 0, 0));
      //strip.setPixelColor(3, strip.Color(0, 0, 0));
      while(i < I2C_BUFFER_SIZE){
        Wire.write(0);
        i++;
      }
      break;
    case SEND_STATES:
      //strip.setPixelColor(1, strip.Color(0, 0, 0));
      //strip.setPixelColor(2, strip.Color(255, 0, 0));
      //strip.setPixelColor(3, strip.Color(0, 0, 0));
      while(i < AMMOUNT_KEYS){
        Wire.write(pressed[i]);
        //Wire.write(0);
        i++;
      }
      while(i < I2C_BUFFER_SIZE){
        Wire.write(0);
        i++;
      }
      //mode = IDLE;
      break;
    default:
      //strip.setPixelColor(1, strip.Color(0, 0, 0));
      //strip.setPixelColor(2, strip.Color(0, 0, 0));
      //strip.setPixelColor(3, strip.Color(0, 0, 255));
      while(i < I2C_BUFFER_SIZE){
        Wire.write(0);
        i++;
      }
      //mode = IDLE;
      break;
  }
}

void rainbow(uint8_t wait) {
  if(pixelInterval != wait)
    pixelInterval = wait;                   
  for(uint16_t i=0; i < pixelNumber; i++) {
    strip.setPixelColor(i, Wheel((i + pixelCycle) & 255)); //  Update delay time  
  }
  strip.show();                             //  Update strip to match
  pixelCycle++;                             //  Advance current cycle
  if(pixelCycle >= 256)
    pixelCycle = 0;                         //  Loop the cycle back to the begining
}

void lightingSetup(){
  strip.begin();           // INITIALIZE NeoPixel strip object (REQUIRED)
  strip.show();            // Turn OFF all pixels ASAP
  strip.setBrightness(LED_BRIGHTNESS); // Set BRIGHTNESS to about 1/5 (max = 255)
}

uint32_t Wheel(byte WheelPos) {
  WheelPos = 255 - WheelPos;
  if(WheelPos < 85) {
    return strip.Color(255 - WheelPos * 3, 0, WheelPos * 3);
  }
  if(WheelPos < 170) {
    WheelPos -= 85;
    return strip.Color(0, WheelPos * 3, 255 - WheelPos * 3);
  }
  WheelPos -= 170;
  return strip.Color(WheelPos * 3, 255 - WheelPos * 3, 0);
}

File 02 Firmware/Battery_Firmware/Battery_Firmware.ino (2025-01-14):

/**
 * if Stuff no work, check this: https://github.com/T-vK/ESP32-BLE-Keyboard/issues/169
 */
#include "BleKeyboard.h"
#include <Wire.h>
#include <memory>
#include "esp_bt.h"

#define BAT_V_PIN 2
#define PIN_SDA 6
#define PIN_SCL 7

#define ADDR_I2C 0x69
#define DELAY_FOR_GET_BATTERY_LEVEL 10000

enum
{
  RID_KEYBOARD = 1,
  RID_GAMEPAD,
  RID_CONSUMER_CONTROL, // Media, volume etc ..
};

BleKeyboard bleKeyboard("Typeuwu", "FG Labs", 69);

uint8_t delayTime = 60;
uint64_t time_prev = 0;

bool softDisableFlag = 0;

String sendString;
//KeyReport reportBuffer;
std::vector <KeyReport *> reportBuffer;

void Keyboard_print(String text);
void Keyboard_send_buffer();
void clear_send_buffer();
void receiveEvent(int howMany);

void setup() {
  Serial.begin(115200);
  Serial.println("Starting BLE work!");
  bleKeyboard.begin();
  bleKeyboard.setBatteryLevel(get_battery_level());
  Wire.setPins(PIN_SDA, PIN_SCL);
  Wire.begin(ADDR_I2C);
  Wire.onReceive(receiveEvent);
  time_prev = millis();
}



void loop() {
  if(bleKeyboard.isConnected() && reportBuffer.size() > 0) {
    Keyboard_send_buffer();
  }
  else if(reportBuffer.size() > 0){
    for(int i = 0; i < reportBuffer.size(); i++){
      delete reportBuffer.at(i);          //prevent memory leaks (hopefully...)
    }
    reportBuffer.clear();
  }

  if(millis() > (time_prev + DELAY_FOR_GET_BATTERY_LEVEL)){
    time_prev = millis();
    bleKeyboard.setBatteryLevel(get_battery_level());
    Serial.println("Updated  Battery level");
  }

  if(softDisableFlag){
    esp_bt_controller_disable();
    esp_deep_sleep_start();
    //while(softDisableFlag) delay(100);
  }

}

void receiveEvent(int howMany){
  reportBuffer.push_back(new KeyReport);
  KeyReport *tmp = reportBuffer.at(reportBuffer.size()-1);
  uint8_t reportID = 0;
  while(Wire.available()){
    reportID = Wire.read();
    switch(reportID){
      case RID_KEYBOARD:
        tmp->modifiers = Wire.read();
        tmp->keys[0] = Wire.read();
        tmp->keys[1] = Wire.read();
        tmp->keys[2] = Wire.read();
        tmp->keys[3] = Wire.read();
        tmp->keys[4] = Wire.read();
        tmp->keys[5] = Wire.read();
        break;
      case 15:
        softDisableFlag = Wire.read();
        if(softDisableFlag != 0) softDisableFlag = true;
        break;
      default:
        Wire.read();
        break;
    }
    // Read in format ReportID,modifier,keycodes[6]
  }
}

void Keyboard_send_buffer(){
  Serial.println("Sending Buffer");
  for(int i = 0; i < reportBuffer.size(); i++){
    if((i%4)==0 && i > 0){
      delay(delayTime);
    }
    bleKeyboard.sendReport(reportBuffer.at(i));
    //bleKeyboard.releaseAll();
    for(int n = 0; n < 6; n++){
      Serial.print(reportBuffer.at(i)->keys[n]);
    }
    Serial.println(reportBuffer.at(i)->modifiers);
  }

  for(int i = 0; i < reportBuffer.size(); i++){
    delete reportBuffer.at(i);          //prevent memory leaks (hopefully...)
  }
  reportBuffer.clear();
}

uint8_t get_battery_level(){
  return (uint8_t)map(analogRead(BAT_V_PIN), 0, 1023, 0, 100);
}

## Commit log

2023-07-21 Board V1
    [The Typeuwu.kicad_sch, connectors.kicad_sch, controller.kicad_sch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]
2023-07-26 Board V1 Rev 2
    [bom.csv, connectors.kicad_sch, controller.kicad_sch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]
2025-01-14 added first module
    [Numpad.kicad_pcb, Numpad.kicad_sch, Warenkorb_Jul29_0317.xls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]
2025-01-14 firmware working version and 3D update
    [Base 1.SLDPRT, Base 1.STL, Base 2.STL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]
2025-01-14 started on Battery module
    [Battery.kicad_pcb, Battery.kicad_sch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]
2025-01-14 update to I2C and MIDI Interface
    [Base Binder.SLDPRT, Battery.kicad_sch, Plate 1.SLDPRT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]
2025-01-14 first rev of Battery module
    [Battery.kicad_pcb, Battery.kicad_sch, bom.csv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]
2025-01-14 started battery firmware
    [Battery.kicad_pcb, Battery.kicad_sch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]
2025-01-14 battery firmware done and updated Typeuwu firmware
    now supports more commands
    [4-Pin Header - Female - 2.54mm.step, 4-Pin Header - Male - 2.54mm.step, Base 1.STL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]
2025-01-14 updated readme and cleanup
    [4-Pin Header - Female - 2.54mm.step, 4-Pin Header - Male - 2.54mm.step, Base 1.STL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]
